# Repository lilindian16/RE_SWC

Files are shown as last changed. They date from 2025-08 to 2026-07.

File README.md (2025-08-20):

# RE_SWC - Car Stereo Volume Knob

_The RE_SWC (Rotary Encoder Steering Wheel Controller) is a plug-and-play kit to add a volume knob back into your car_

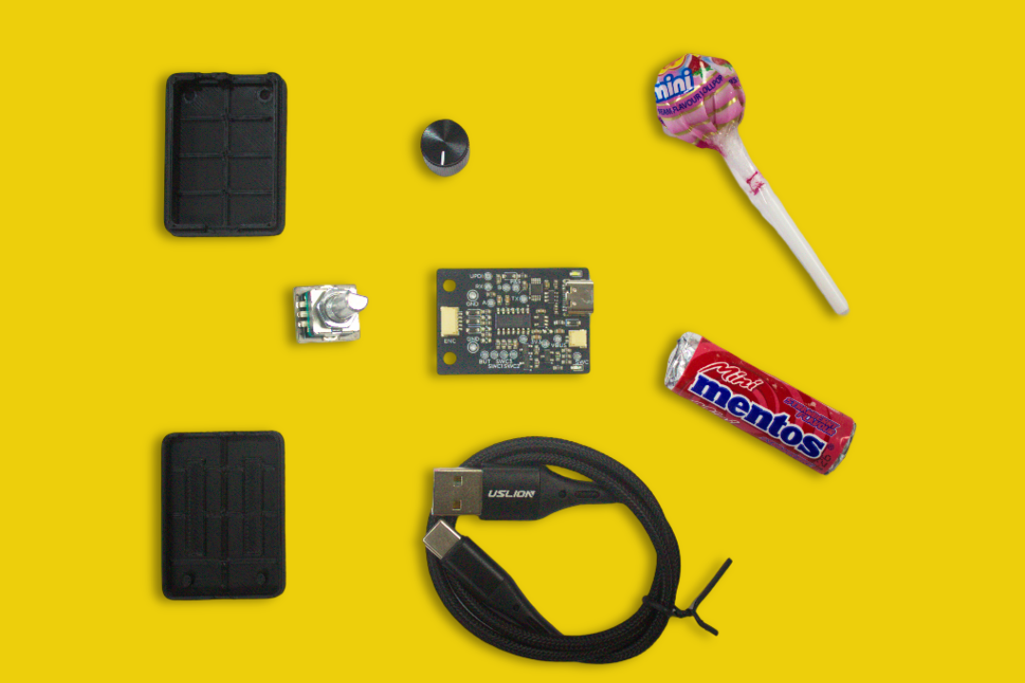
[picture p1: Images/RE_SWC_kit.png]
RE_SWC Product Render




## Features:

- Simple, plug-and-play solution. Mount the volume knob to a panel in the car, solder two wires into your stereo's steering wheel control input and you are good to go
- USB powered. Most headunits have female USB connectors for you to plug this into and power up
- MCU: ATtiny414 - Industrial rated
- Interrupt-driven firmware results in a smooth, user-friendly experience
- Built-in USB to UPDI serial converter for easy programming. If you want to tinker with firmware, do so
- Open source hardware and firmware. This includes all design files, BOM, firmware, etc

## Functions:

- Volume +/-
- Button short press
- Button long press
- Button double press to activate learning mode for headunit

## Compatibility:

The [Hardware Report](https://docs.google.com/spreadsheets/d/1KuhRTHHPlsPpQyRziJOaQv1jJqykjcSSAFU2pcPYcbk/edit?usp=sharing) for this project includes a compatibility matrix. As more people adopt this product, we can build a comprehensive list of compatible devices.

Most headunits supporting steering wheel control input learning/remapping should support this device.

Note: I cannot guarantee this will work with your headunit - there is a decent chance it should if I list it as compatible

## User Guide

The [User Guide](Docs/RE_SWC%20USER%20GUIDE.pdf) can be found in the Docs subfolder of this repository

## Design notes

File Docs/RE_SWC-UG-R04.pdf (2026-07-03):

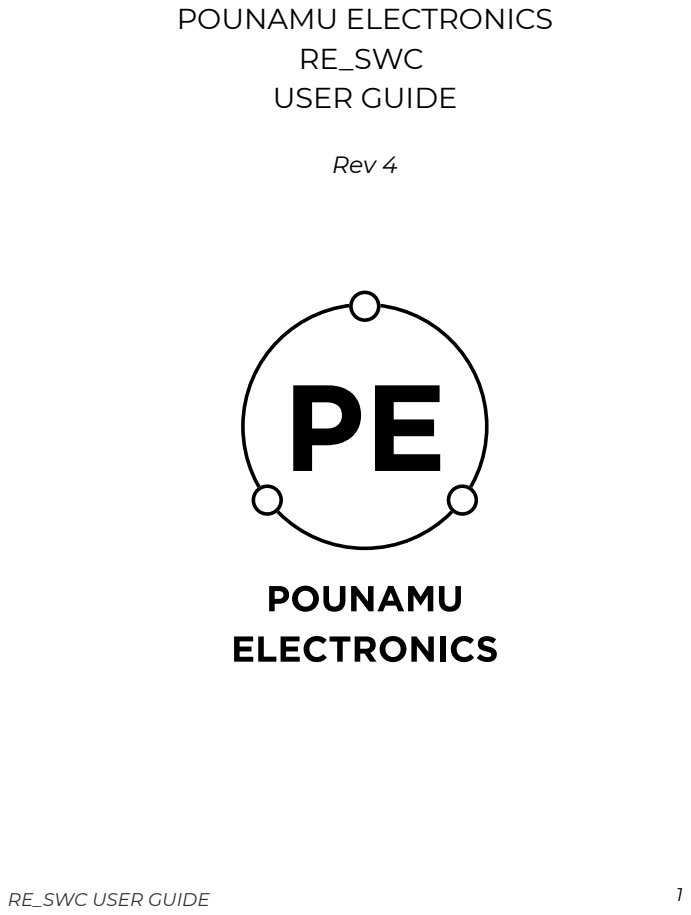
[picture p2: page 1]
RE_SWC USER GUIDE; POUNAMU ELECTRONICS RE_SWC USER GUIDE; Rev 4

3 | OVERVIEW
4 | INSTALLATION GUIDES
| 4 INSTALLATION - GENERIC RESISTIVE
| 5 INSTALLATION - JVC
| 6 INSTALLATION - KENWOOD
| 7 INSTALLATION - ALPINE
| 8 INSTALLATION - PIONEER
| 9 INSTALLATION - USB HID
| 10 INSTALLATION - SONY
11 | CONFIGURATION - HEADUNIT SELECTION
12 | HEADUNIT LEGEND
13 | DEFAULT FUNCTIONS
14 | ASSEMBLY TIPS
15 | VOLUME KNOB DIMESIONS
16 | TROUBLESHOOTING
17 | RE_SWC SPECS
18 | DISCLAIMERS
19 | COMPLIANCE
20 | DOCUMENT REVISION HISTORY

2

### Contents

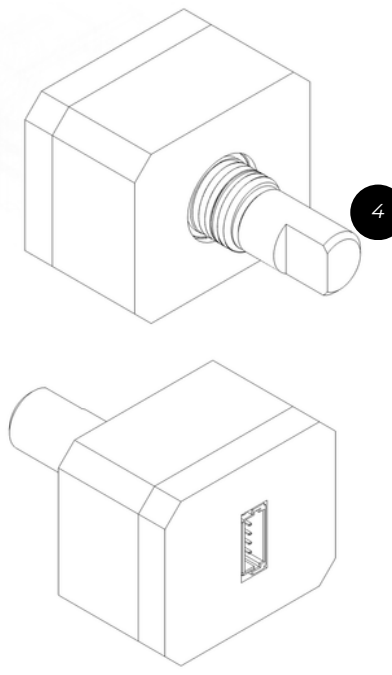
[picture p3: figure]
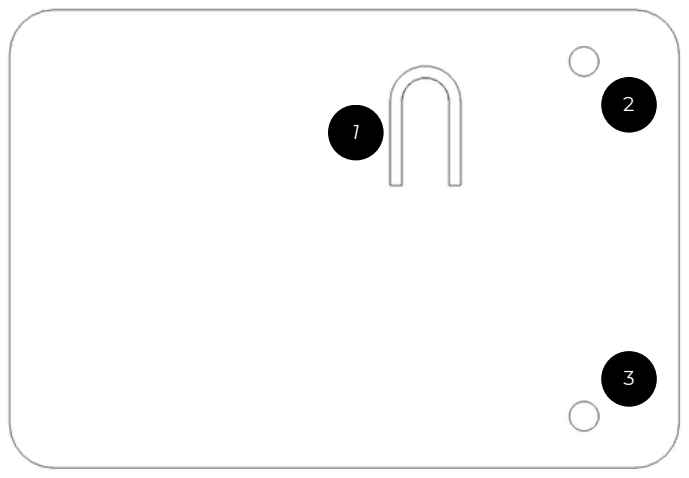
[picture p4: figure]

1. UPDATE BUTTON | 2. WHITE STATUS LIGHT
3. RED POWER LIGHT | 4. DIA 6mm ENCODER SHAFT
RE_SWC USER GUIDE | 3

### OVERVIEW

4

### INSTALLATION - GENERIC RESISTIVE

Solder the RED wire from the 2-pin connector on the RE_SWC kit to your headunit’s steering wheel control input pin (generally labelled KEY1 or KEY2)
If you purchased the 3.5mm patch cable, this will be the tip of the TRS jack
Solder the BLACK wire from the 2-pin connector into your harness if your headunit requires a reference for the SWC input (sometimes labelled ST REMOTE GND)
If you purchased the 3.5mm patch cable, this will be the sleeve of the TRS jack
Power the kit with a USB C cable.
NOTE: This kit requires 5V USB power only The RED power indicator on the RE_SWC will illuminate and stay on

Note: If your headunit requires holding the steering wheel control input when setting functions, double press the volume knob to enter learning mode (indicated with the WHITE status light flashing). The RE_SWC kit will hold the output for 4 seconds
e.g. rotating the knob clockwise once will result in the RE_SWC kit holding the clockwise output for 4 seconds.
Repeat this process to program all functions

5

### INSTALLATION - JVC

Solder the RED wire from the 2-pin connector on the RE_SWC kit to your headunit’s steering wheel control input pin (normally a blue and yellow wire)
If you purchased the 3.5mm patch cable, this will be the tip of the TRS jack
Power the kit with a USB C cable.
NOTE: This kit requires 5V USB power only The RED power indicator on the RE_SWC will illuminate and stay on
The RE_SWC kit will operate without any further configuration on your headunit

6

### INSTALLATION - KENWOOD

Solder the RED wire from the 2-pin connector on the RE_SWC kit to your headunit’s steering wheel control input pin (normally a blue and yellow wire)
If you purchased the 3.5mm patch cable, this will be the tip of the TRS jack
Power the kit with a USB C cable.
NOTE: This kit requires 5V USB power only The RED power indicator on the RE_SWC will illuminate and stay on
The RE_SWC kit will operate without any further configuration on your headunit

7

### INSTALLATION - ALPINE

Plug the RE_SWC into your unit using the 3.5mm patch cable
You can make a compatible 3.5mm patch cable yourself by soldering the red wire from the 2-pin connector on the RE_SWC kit to the tip of the 3.5mm jack. Leave the ring and sleeve floating
Power the kit with a USB C cable.
NOTE: This kit requires 5V USB power only The RED power indicator on the RE_SWC will illuminate and stay on
The RE_SWC kit will operate without any further configuration on your headunit

8

### INSTALLATION - PIONEER

Plug the RE_SWC into your unit using the 3.5mm patch cable
You can make a compatible 3.5mm patch cable yourself by soldering the red wire from the 2-pin connector on the RE_SWC kit to the tip of the 3.5mm jack. Leave the ring and sleeve floating
Power the kit with a USB C cable.
NOTE: This kit requires 5V USB power only The RED power indicator on the RE_SWC will illuminate and stay on
Ensure “With Adapter” is set in the Steering Wheel Controls menu on your headunit
The RE_SWC kit will operate without any further configuration on your headunit

9

### INSTALLATION - USB HID

Connect the RE_SWC kit to your device with a USB C cable (must support data & 5V power) Note: Do not use this device with any power source higher than standard USB 5V
The RED power indicator on the RE_SWC will illuminate and stay on

10

### INSTALLATION - SONY

Plug the RE_SWC into your unit using the 3.5mm patch cable
You can make a compatible 3.5mm patch cable yourself by soldering the red wire from the RE_SWC kit to the tip of the 3.5mm jack. Leave the ring and sleeve floating
Power the kit with a USB C cable.
NOTE: This kit requires 5V USB power only The RED power indicator on the RE_SWC will illuminate and stay on
In the Steering Wheel Controls menu, set the [Custom] switch to [OFF]
On some units, you may need to set it to be “With Adapter”
The RE_SWC kit will operate without any further configuration on your headunit

11

### CONFIGURATION - HEADUNIT SELECTION

Ensure RE_SWC is not powered
Press and hold the volume knob. Connect power to the RE_SWC while keeping the volume knob held
Release the volume knob after the WHITE status light is illuminated
Press the volume knob once. The WHITE status light will flash once. Headunit number 1 is now programmed. Repeat this step until the desired headunit number is reached - refer to the headunit legend
When the desired headunit number is entered, press and hold the volume knob. The WHITE status light will flash. Release the volume knob. The RE_SWC will flash x times where x is the headunit number entered

12

### HEADUNIT LEGEND

HEADUNIT NUMBER | HEADUNIT TYPE / BRAND

1 GENERIC RESISTIVE

2 JVC

3 KENWOOD

4 ALPINE

5 PIONEER

6 USB HID

7 SONY

13

### DEFAULT FUNCTIONS

INPUT | OUTPUT
Volume Knob CW | Volume +
Volume Knob CCW | Volume -
Button Short Press | Mute
Button Long Press | Next Track
Button Double Press (Generic Resistive mode) | Enable Learning Mode
Button Double Press (Other Modes) | Previous Track

RE_SWC USER GUIDE | 14

### ASSEMBLY TIPS

Mounting the knob
Drill a pilot hole between 1 and 3mm in diameter Widen the hole to 7.5mm
Mount the knob into the hole and secure with the included washer and nut

Powering the RE

_

SWC
The RE_SWC uses 5V USB power. Do not use any higher voltage
The RE_SWC boots up almost instantaneously. You can power the device with a switched 5V USB power supply. Configuration settings are retained between power cycles

Note
The RE_SWC will be shipped pre-configured in the mode selected during the checkout process for a plug-and-play setup

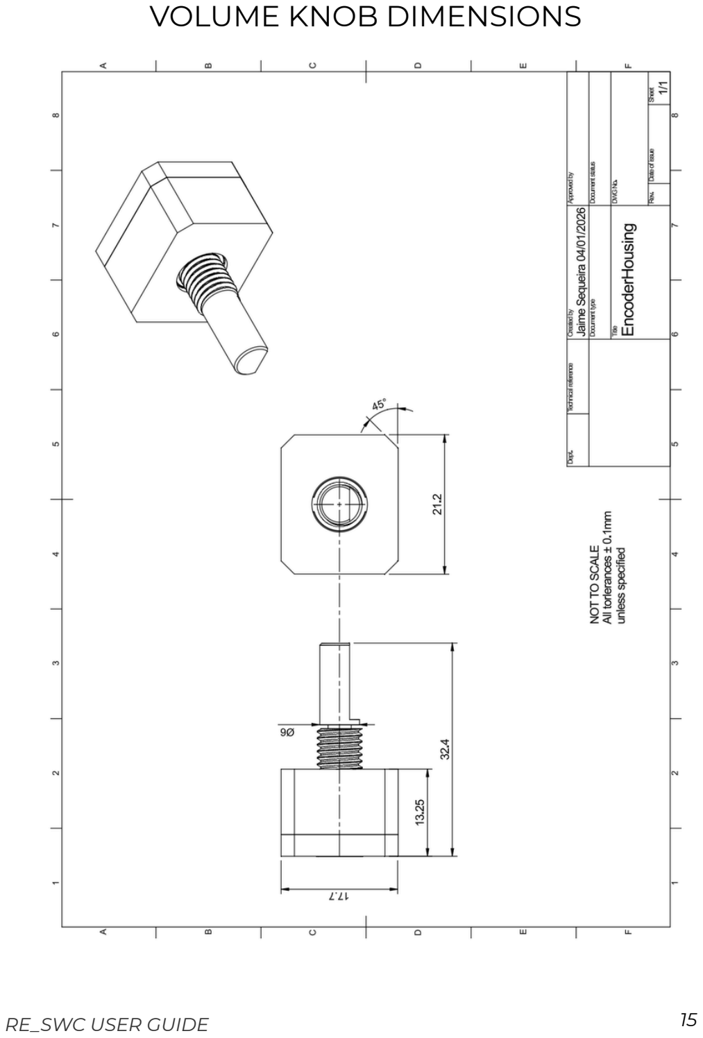
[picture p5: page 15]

RE_SWC USER GUIDE | 15

### VOLUME KNOB DIMENSIONS

16

### TROUBLESHOOTING

The RED power light is off
Ensure you are powering the kit with 5V USB power

The RED power light is on but the WHITE status light does not flash when I use the knob Ensure the 5-pin connector harness for the knob is seated correctly and inserted fully into the knob and the kit

The WHITE status light flashes when I turn the knob but my headunit does nothing
Ensure you have set the kit in the correct headunit mode
Ensure the RED wire from the 2-pin connector is soldered properly into your headunit’s harness

My headunit shows the volume increasing but the volume of my music doesn’t change in USB HID mode
Some Android headunits do not route USB volume commands to the correct hardware. Revert to using the Resistive SWC mode with Key1 / Key 2 input wire instead

### RE_SWC SPECS

Input
Power: 5V / 100mA USB-C
SWC Header: 5V max. Do not connect to 12V signal

CONNECTORS
VOLUME KNOB: JST SHR-05V-S-B SWC OUT: JST SHR-02V-S-B

MCU:
WCH CH32X035F8U6

Digital Rheostat:
MCP4131-104E/SN
SPI @ 250kHz
RE_SWC USER GUIDE | 17

18

### DISCLAIMERS

Pounamu Electronics is not affiliated or associated with any headunit manufacturers or brands
Pounamu Electronics is not affiliated or associated with the USB Implementers Forum (USB-IF)

19

### COMPLIANCE

FCC Compliance Statement
This device complies with Part 15 of the FCC Rules. Operation is subject to the following two
conditions:
1. This device may not cause harmful interference, and
2. this device must accept any interference received, including interference that may cause undesired operation.

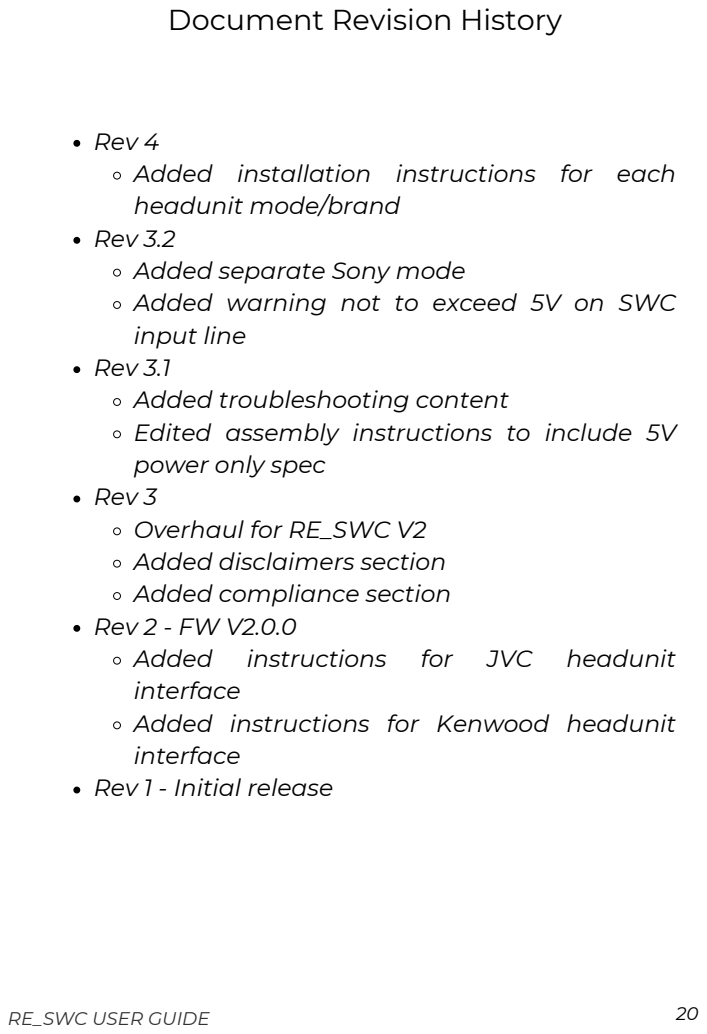
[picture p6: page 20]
RE_SWC USER GUIDE

Document Revision History

Rev 4
Added installation instructions for each
headunit mode/brand
Rev 3.2
Added separate Sony mode
Added warning not to exceed 5V on SWC
input line
Rev 3.1
Added troubleshooting content
Edited assembly instructions to include 5V
power only spec
Rev 3
Overhaul for RE_SWC V2
Added disclaimers section
Added compliance section
Rev 2 - FW V2.0.0
Added instructions for JVC headunit
interface
Added instructions for Kenwood headunit
Rev 1 - Initial release

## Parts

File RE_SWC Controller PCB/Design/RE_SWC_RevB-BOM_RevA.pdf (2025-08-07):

### RE_SWC_RevB - BOM BOM Revision: A

Release: 17/07/2025 Designator | Qty Manufacturer | MPN | LCSC PN Description / Value | Footprint | Datasheet C101,C102,C105,C109 | 4 | YAGEO | CC0603KRX7R9BB104 | C14663 | 100n | C_0603 | https://jlcpcb.com/api/file/downloadByFileSystemAccessId/8579707083955945472 C103,C104 | 2 | Samsung Electro-Mechanics | CL10A106MA8NRNC | C96446 | 10u | C_0603 | https://datasheet.lcsc.com/lcsc/2304140030_Samsung-Electro-Mechanics-CL10A106MA8NRNC_C96446.pdf C106,C107,C108 | 3 | FH (Guangdong Fenghua Advanced Tech) | 0603B103K500NT | C57112 | 10n | C_0603 | https://jlcpcb.com/api/file/downloadByFileSystemAccessId/8579707164920893440 R101,R102,R103,R104,R105,R106,R107,R109,R118,R121,R122 | 11 UNI-ROYAL(Uniroyal Elec) | 0603WAF3300T5E | C23138 | 330R | R_0603 | https://jlcpcb.com/api/file/downloadByFileSystemAccessId/8579706223213461504 R110 | 1 | UNI-ROYAL(Uniroyal Elec) | 0603WAF1001T5E | C21190 | 1k | R_0603 | https://jlcpcb.com/api/file/downloadByFileSystemAccessId/8579706098733010944 R111,R115,R116,R117,R119,R120 | 6 | UNI-ROYAL(Uniroyal Elec) | 0603WAF5101T5E | C23186 | 5k1 | R_0603 | https://jlcpcb.com/api/file/downloadByFileSystemAccessId/8579706277024620544 R112 | 1 | UNI-ROYAL(Uniroyal Elec) | 0603WAF0000T5E | C21189 | 0R | R_0603 | https://jlcpcb.com/api/file/downloadByFileSystemAccessId/8578255895094087680 D101,D109 | 2 | Guangdong Hottech | 1N5819WS | C191023 | 1N5819WS | D_SOD-323_HandSoldering | https://lcsc.com/datasheet/lcsc_datasheet_2409300937_Guangdong-Hottech-1N5819WS_C191023.pdf D102,D105,D106 | 3 | ElecSuper | UDD32C03L01-ES | C5180209 | UDD32C03L01-ES | D_SOD-323_HandSoldering | https://lcsc.com/datasheet/lcsc_datasheet_2504101957_ElecSuper-UDD32C03L01-ES_C5180209.pdf D103 | 1 | Hubei KENTO Elec | KT-0603R | C2286 | LED_RED | LED_0603_HandSolder | https://datasheet.lcsc.com/lcsc/1810231112_Hubei-KENTO-Elec-KT-0603R_C2286.pdf D104 | 1 | Hubei KENTO Elec | KT-0603W | C2290 | LED_WHITE | LED_0603_HandSolder | https://jlcpcb.com/api/file/downloadByFileSystemAccessId/8550724001388785664
F101 | 1 | BHFUSE | BSMD0603-010-24V | C883089 | BSMD0603-010-24V | Fuse_0603_HandSolder | https://www.lcsc.com/datasheet/lcsc_datasheet_2504101957_BHFUSE-BSMD0603-010-24V_C883089.pdf Q101,Q102,Q103 | 3 | Alpha & Omega Semicon | AO3400A | C20917 | AO3400A NMOS | SOT-23 | https://lcsc.com/datasheet/lcsc_datasheet_2410121838_Alpha---Omega-Semicon-AO3400A_C20917.pdf U101 | 1 | Texas Instruments | TPS70933DBVR | C89347 | TPS70933DBVR | SOT-23-5 | https://lcsc.com/datasheet/lcsc_datasheet_2410121952_TI-TPS70933DBVR_C89347.pdf U102 | 1 | Microchip Tech | ATTINY414-SSNR | C189365 | ATtiny414-SSNR | SOIC-14_3.9x8.7mm_P1.27mm | http://ww1.microchip.com/downloads/en/DeviceDoc/40001912A.pdf U103 | 1 | WCH(Jiangsu Qin Heng) | CH340X | C3035748 | CH340X USB UART | MSOP-10_3x3mm_P0.5mm | https://jlcpcb.com/api/file/downloadByFileSystemAccessId/8618866959262109696 U106 | 1 | ST | USBLC6-2SC6 | C7519 | USBLC6-2SC6 | SOT-23-6 | https://lcsc.com/datasheet/lcsc_datasheet_2411121100_TECH-PUBLIC-USBLC6-2SC6_C2827654.pdf
J101 | 1 | G-Switch | GT-USB-7010ASV | C2988369 | GT-USB-7010ASV | G-Switch_GT-USB-7010ASV | https://www.usb.org/sites/default/files/documents/usb_type-c.zip
J104 | 1 | JST | SM05B-SRSS-TB(LF)(SN) | C136657 | SM05B-SRSS-TB | JST_SH_SM05B-SRSS-TB | https://lcsc.com/product-detail/Wire-To-Board-Connector_JST-SM05B-SRSS-TB-LF-SN_C136657.html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,JST%20SM05B%2DSRSS%2DTB(LF)(SN),-Custom%20Cables
J106 | 1 | JST | SM02B-SRSS-TB(LF)(SN) | C160402 | SM02B-SRSS-TB | JST_SH_SM02B-SRSS-TB | https://www.lcsc.com/datasheet/lcsc_datasheet_2304140030_JST-SM02B-SRSS-TB-LF-SN_C160402.pdf

Revision Notes Rev A: Initial release

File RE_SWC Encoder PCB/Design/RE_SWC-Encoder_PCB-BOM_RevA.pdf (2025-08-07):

RE_SWC-Encoder_PCB - BOM
BOM Revision: A
Release: 17/07/2025 Designator | Qty Manufacturer | MPN | LCSC PN Description / Value | Footprint | Datasheet
SW101 | 1 | CTR | ED11305M-FB18.5A10-E20-160-G219 | C19712528 Rotary Encoder | Rotary_Encoder:RotaryEncoder_Bourns_Vertical_PEC12R-3x17F-Sxxxx | https://lcsc.com/datasheet/lcsc_datasheet_2410121342_CTR-ED11305M-FB18-5A10-E20-160-G219_C19712528.pdf
J101 | 1 | JST | BM05B-SRSS-TBT(LF)(SN) | C265092 | BM05B-SRSS-TBT(LF)(SN) | Connector_JST:JST_SH_BM05B-SRSS-TB_1x05-1MP_P1.00mm_Vertical | https://www.lcsc.com/datasheet/lcsc_datasheet_2004071004_JST-BM05B-SRSS-TBT-LF-SN_C265092.pdf

Revision Notes
Rev A: Initial release

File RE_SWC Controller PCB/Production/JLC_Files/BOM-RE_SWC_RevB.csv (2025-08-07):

Comment | Designator | Footprint | LCSC | Quantity
SM05B-SRSS-TB | J104 | JST_SH_SM05B-SRSS-TB_1x05-1MP_P1.00mm_Horizontal | C136657 | 1
100n | C102,C105,C109 | C_0603_1608Metric | C14663 | 3
SM02B-SRSS-TB | J106 | JST_SH_SM02B-SRSS-TB_1x02-1MP_P1.00mm_Horizontal | C160402 | 1
ATtiny414-SSNR | U102 | SOIC-14_3.9x8.7mm_P1.27mm | C189365 | 1
1N5819WS | D101,D109 | D_SOD-323_HandSoldering | C191023 | 2
AO3400A | Q101,Q102,Q103 | SOT-23 | C20917 | 3
0R | R112 | R_0603_1608Metric | C21189 | 1
1k | R110 | R_0603_1608Metric | C21190 | 1
LED_RED | D103 | LED_0603_1608Metric_Pad1.05x0.95mm_HandSolder | C2286 | 1
LED_WHITE | D104 | LED_0603_1608Metric_Pad1.05x0.95mm_HandSolder | C2290 | 1
330R | R101,R102,R103,R104,R105,R106,R107,R109,R118,R121,R122 | R_0603_1608Metric | C23138 | 11
5k1 | R111,R115,R116,R117,R119,R120 | R_0603_1608Metric | C23186 | 6
GT-USB-7010ASV | J101 | USB_C_Receptacle_G-Switch_GT-USB-7010ASV | C2988369 | 1
CH340X | U103 | MSOP-10_3x3mm_P0.5mm | C3035748 | 1
UDD32C03L01-ES | D102,D105,D106 | D_SOD-323_HandSoldering | C5180209 | 3
10n | C106,C107,C108 | C_0603_1608Metric | C57112 | 3
USBLC6-2SC6 | U106 | SOT-23-6 | C7519 | 1
BSMD0603-010-24V | F101 | Fuse_0603_1608Metric_Pad1.05x0.95mm_HandSolder | C883089 | 1
TPS70933DBVR | U101 | SOT-23-5 | C89347 | 1
10u | C103,C104 | C_0603_1608Metric | C96446 | 2

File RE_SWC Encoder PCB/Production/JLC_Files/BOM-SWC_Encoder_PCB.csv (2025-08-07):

Comment | Designator | Footprint | LCSC | Quantity
Rotary Encoder | SW101 | RotaryEncoder_Bourns_Vertical_PEC12R-3x17F-Sxxxx | C19712528 | 1
BM05B-SRSS-TBT(LF)(SN) | J101 | JST_SH_BM05B-SRSS-TB_1x05-1MP_P1.00mm_Vertical | C265092 | 1

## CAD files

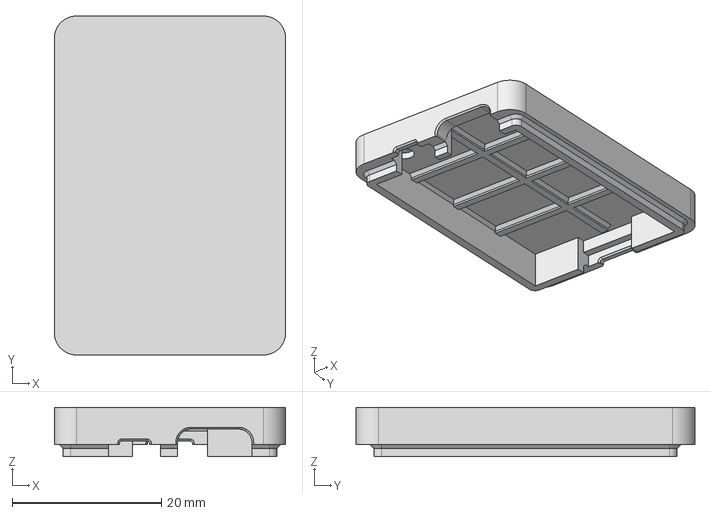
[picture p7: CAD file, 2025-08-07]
RE_SWC Case/FDM/STEP/RE_SWC_FDM_Case_Lid.step
31.0 x 45.4 x 6.60 mm

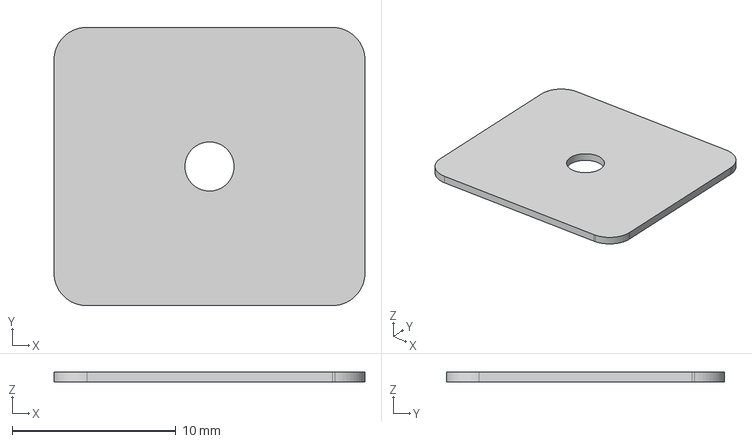
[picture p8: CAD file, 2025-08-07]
RE_SWC Drill Template/RE_SWC_Drill_Template.step
19.0 x 17.0 x 0.6 mm

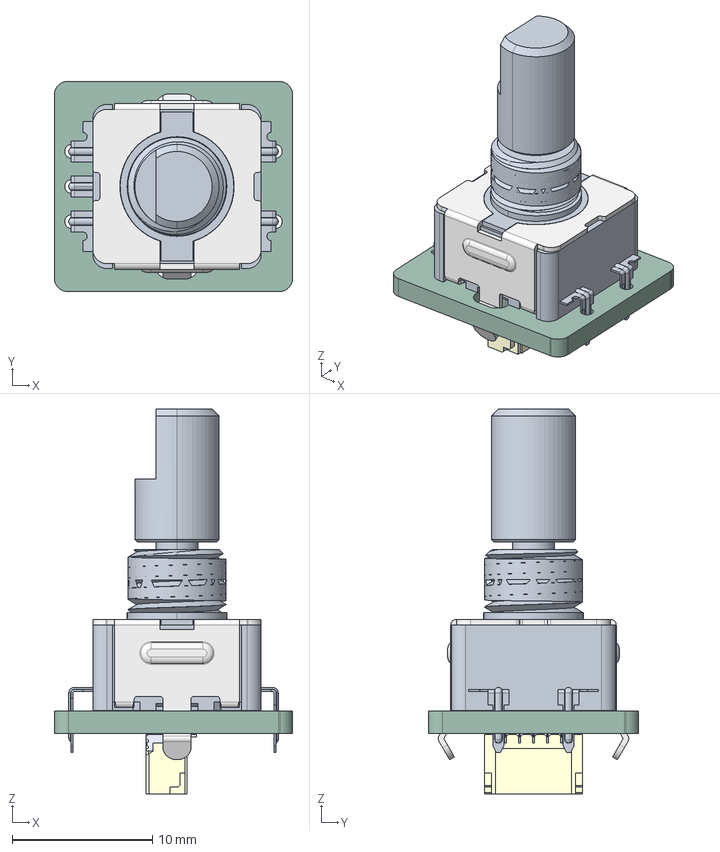
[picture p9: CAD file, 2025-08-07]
RE_SWC Encoder PCB/Design/RE_SWC_Encoder_PCB_RevA.step
17.0 x 15.0 x 27.5 mm
PEC11H-4015F-S0016
BM05B-SRSS-TB(LF)(SN)
SWC_Encoder_PCB_PCB

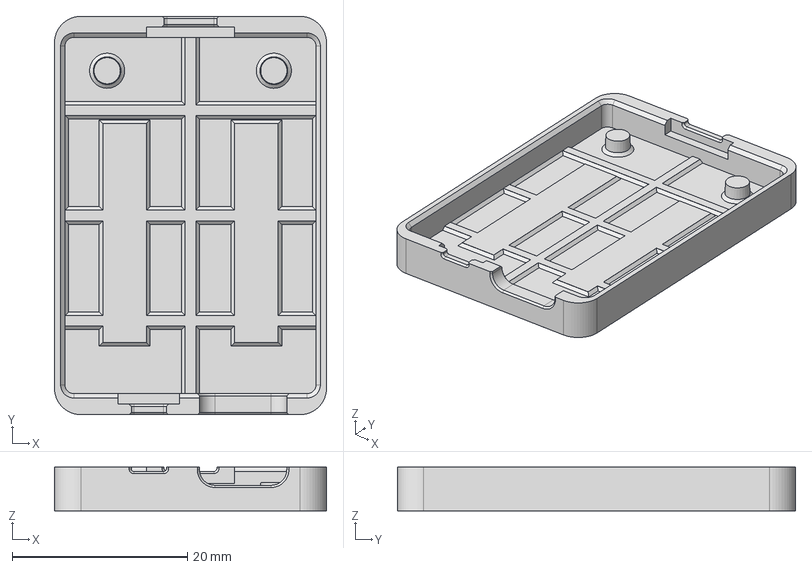
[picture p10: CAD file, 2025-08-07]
RE_SWC Case/FDM/STEP/RE_SWC_FDM_Case_Base.step
31.0 x 45.4 x 5.00 mm

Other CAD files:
RE_SWC Case/FDM/STL/RE_SWC_FDM_Case_Base.stl
RE_SWC Case/FDM/STL/RE_SWC_FDM_Case_Lid.stl
RE_SWC Drill Template/RE_SWC_Drill_Template.stl

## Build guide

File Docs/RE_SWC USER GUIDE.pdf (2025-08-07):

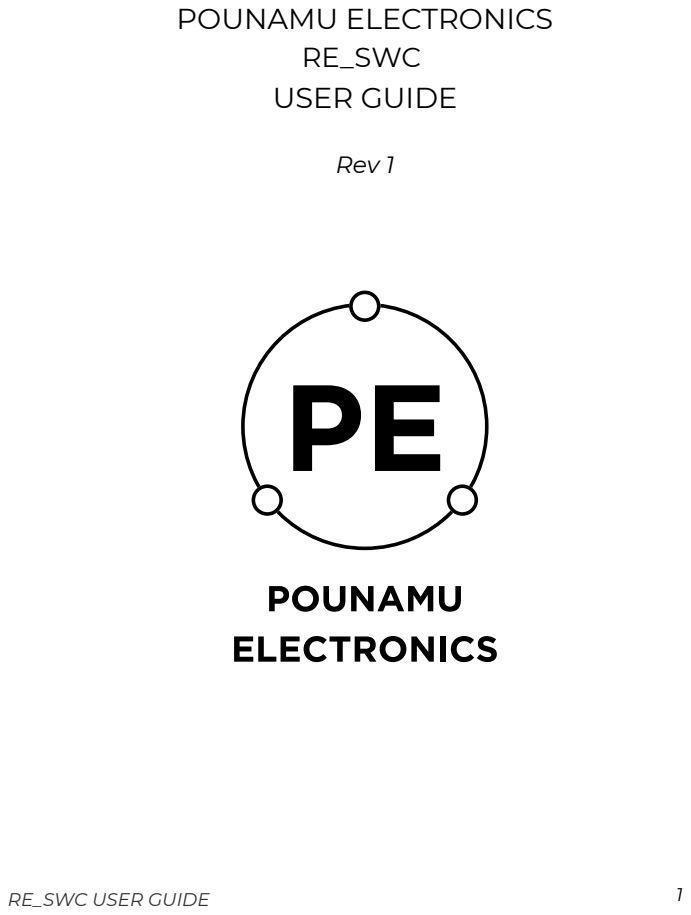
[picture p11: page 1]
RE_SWC USER GUIDE; POUNAMU ELECTRONICS RE_SWC USER GUIDE; Rev 1

3 | OVERVIEW - CONTROLLER BOARD
4 | OVERVIEW - VOLUME KNOB BOARD
5 | ASSEMBLY - STEERING WHEEL CONTROL OUTPUT
6 | ASSEMBLY - VOLUME KNOB CONNECTION
7 | ASSEMBLY - CASE
8 | ASSEMBLY - POWER
9 | HEADUNIT LEARNING - TYPE 1
10 | HEADUNIT LEARNING - TYPE 2
11 | SWC OUTPUT RESISTORS
12 | RE_SWC SPECS
13 | Document Revision History

2

### Contents

1

2

3

4

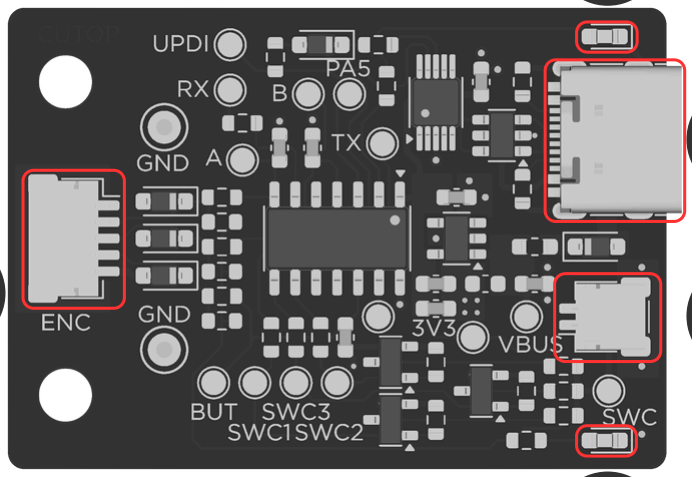
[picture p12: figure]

5

1. VOLUME KNOB CONNECTOR | 2. WHITE STATUS LIGHT
3. USB DATA & POWER IN | 4. STEERING WHEEL CONTROL OUTPUT

### 5. RED POWER LIGHT

RE_SWC USER GUIDE | 3

### OVERVIEW

CONTROLLER BOARD

### OVERVIEW

VOLUME KNOB BOARD

2

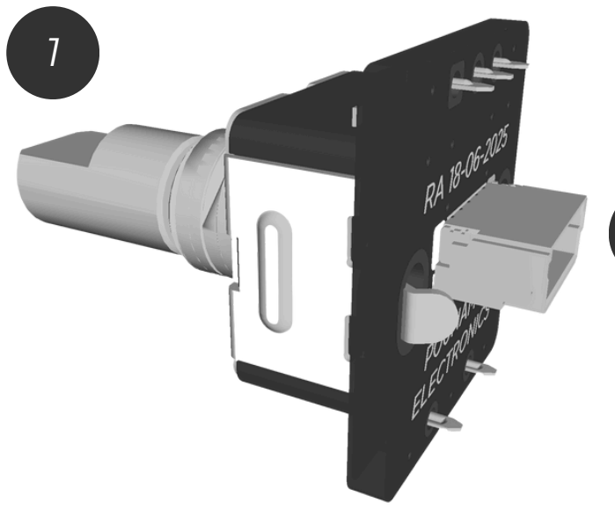
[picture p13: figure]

### 1. VOLUME KNOB

### 2. VOLUME KNOB

CONNECTOR

RE_SWC USER GUIDE | 4

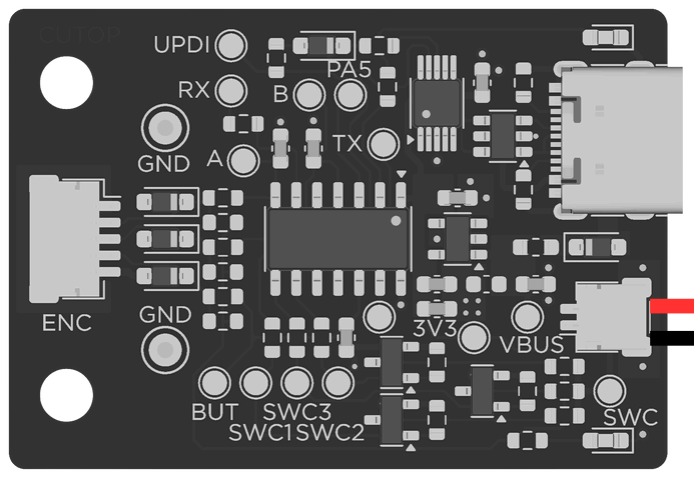
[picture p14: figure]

RE_SWC USER GUIDE | 5

### ASSEMBLY

STEERING WHEEL CONTROL OUTPUT

Solder RE_SWC steering wheel control output to headunit steering wheel control input
RED wire to headunit steering wheel control input (KEY)
BLACK wire to headunit ground
Plug the connector into RE_SWC

GND HEADUNIT

KEY

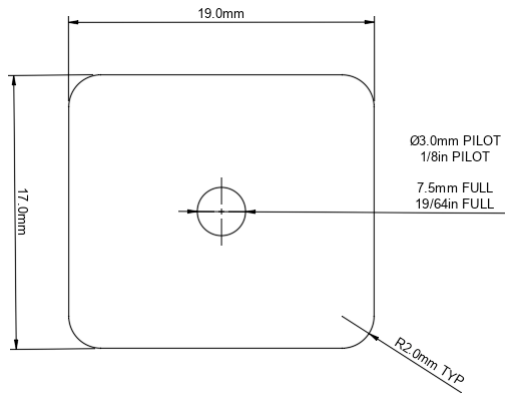
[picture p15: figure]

RE_SWC USER GUIDE | 6

Locate an area to fit your volume knob. Use the drilling template as a guide for clearance
Use the drilling template included in the box or shown below to create a 3mm (1/8in) pilot hole for the volume knob
Open the pilot hole with a 7.5mm (19/64in) drill bit
Plug the 5-pin connector into the volume knob board
Mount the volume knob to your panel. Secure it with the washer and nut included in the kit Plug the 5-pin volume knob connector into RE_SWC

### ASSEMBLY

VOLUME KNOB CONNECTION

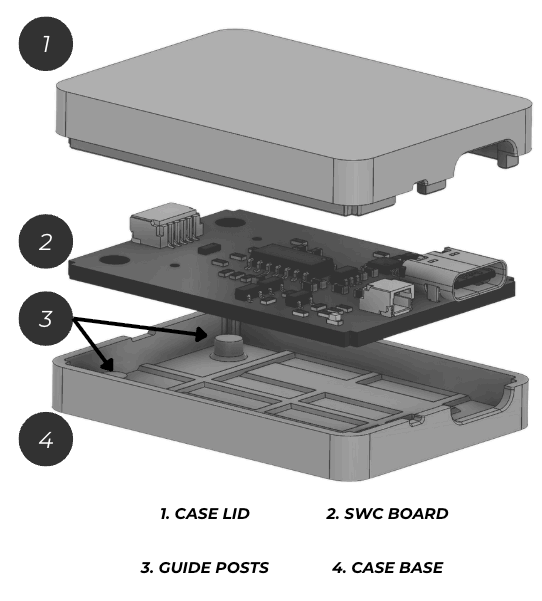
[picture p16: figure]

Ensure the volume knob and SWC output connectors are connected to the controller before proceeding
Lower the SWC board into the case base using the guide posts for alignment and press into place. The volume knob and SWC output connectors will sit flush to the inside edge of the case
Press the case lid into the case base. It should be a tight, snap fit. The connectors will be captive inside the case, unable to be pulled out
RE_SWC USER GUIDE | 7

### ASSEMBLY

CASE

8

### ASSEMBLY

POWER

Plug the included USB-C cable into the RE_SWC When the RE_SWC is powered, the RED power light will illuminate
When working correctly, rotating the volume knob or pressing the volume knob button will result in the WHITE status light illuminating briefly
If the WHITE status light does not illuminate, ensure the volume knob connector is fully seated into both the controller and volume knob boards

### HEADUNIT LEARNING Type 1

Headunit Learning Type 1 is used with headunits that require momentary inputs when learning SWC functions

Open the Steering Wheel Control learning app/setting on your headunit
Select the function you want to program on the headunit e.g. Volume+
Perform the action with your volume knob e.g. for Volume+

, rotate the volume knob clockwise one step
The headunit will confirm that the function has been programmed
Repeat for all required functions
Volume+/-
Button Short Press
Button Long Press
RE_SWC USER GUIDE | 9

10

### HEADUNIT LEARNING Type 2

Headunit Learning Type 2 is used with headunits that require inputs to be held during SWC learning

Enable learning mode on RE_SWC controller by double-pressing the volume knob
The RE_SWC will confirm learning mode is enabled by rapidly flashing the WHITE status light
Select the function you want to program on the headunit e.g. Volume+
Perform the action with your volume knob e.g. for Volume+

, rotate the volume knob clockwise one step
The WHITE status light will illuminate for 4 seconds while the output is held.

IMPORTANT: Do not touch the SWC or headunit during this time to allow the headunit to configure itself

Once the function is programmed, the WHITE status light will be turned off
Repeat for all required functions
Volume+/-
Button Short Press
Button Long Press

11

### SWC OUTPUT RESISTORS

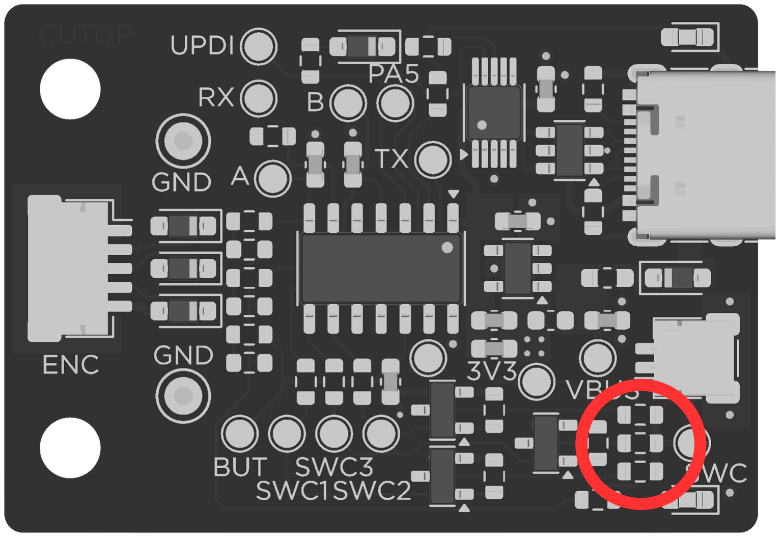
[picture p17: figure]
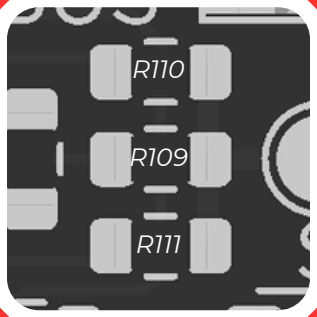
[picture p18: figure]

RESISTOR ID | VALUE | OUTPUT
R110 | 1kΩ ± 1% | SWC OUT 2
R109 | 330Ω ± 1% | SWC OUT 1
R111 | 5.1kΩ ± 1% | SWC OUT 3

### RE_SWC SPECS

Input
5V USB-C
300mA AUTO RESETTING FUSE

Output
SWC OUT 1: 330Ω ± 1%
SWC OUT 2: 1kΩ ± 1%
SWC OUT 3: 5.1kΩ ± 1%

CONNECTORS
VOLUME KNOB: JST SHR-05V-S-B SWC OUT: JST SHR-02V-S-B

MCU:
MICROCHIP ATTINY414
AVR 1 Series
RE_SWC USER GUIDE | 12

### Document Revision History

Rev 1 - Initial release

RE_SWC USER GUIDE | 13

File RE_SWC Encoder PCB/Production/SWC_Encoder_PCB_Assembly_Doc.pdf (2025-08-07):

No | Not specified | 0.01 | mm

# Min hole diameter: Not specified

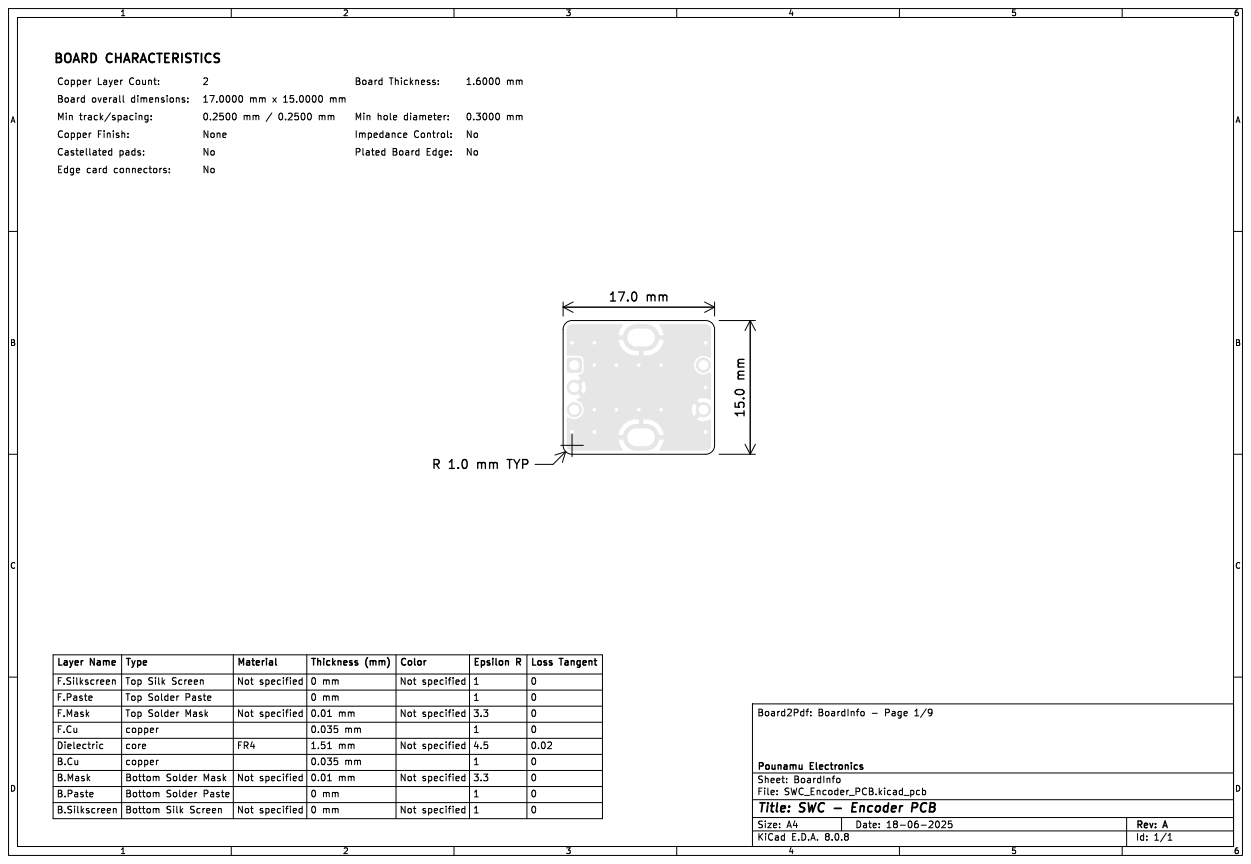
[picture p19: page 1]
D Date: 18-06-2025 KiCad; E.D.A. 8.0.8 Size: A4; Rev: A; File: SWC_Encoder_PCB.kicad_pcb Sheet: BoardInfo Pounamu; Electronics Board2Pdf:; BoardInfo; Page; Board; Thickness:; Impedance; Control:; B.Paste; Edge card; connectors:; Not specified; B.Mask; Epsilon; Board overall; dimensions:; Castellated; pads:; BOARD CHARACTERISTICS; Copper Finish:; None; R 1.0 mm TYP

Copper Layer Count:
Min track/spacing:

Plated Board Edge:

Top Solder Paste | | 0 mm | | | 0 F.Mask Dielectric Layer Name F.Paste F.Cu

Bottom Solder Mask F.Silkscreen | | Screen Top Solder | Screen Mask | | Not specified | | Thickness | (mm) | Color Bottom Silk Not specified B.Silkscreen Not specified | 1 Not specified B.Cu 3.3 | 0 Top Silk 0

Type
copper | | 0.035 mm | | 1 Not specified FR4 | 0

Loss Tangent 1 Material

copper core | | | | | 1 Bottom Solder Paste 4.5

0.035 mm | | | | 0.02 Not specified 0

0.01 mm | | | 3.3 | 0
0 mm | | 1
0 mm | | | 0

Id: 1/1 Title: SWC - Encoder PCB

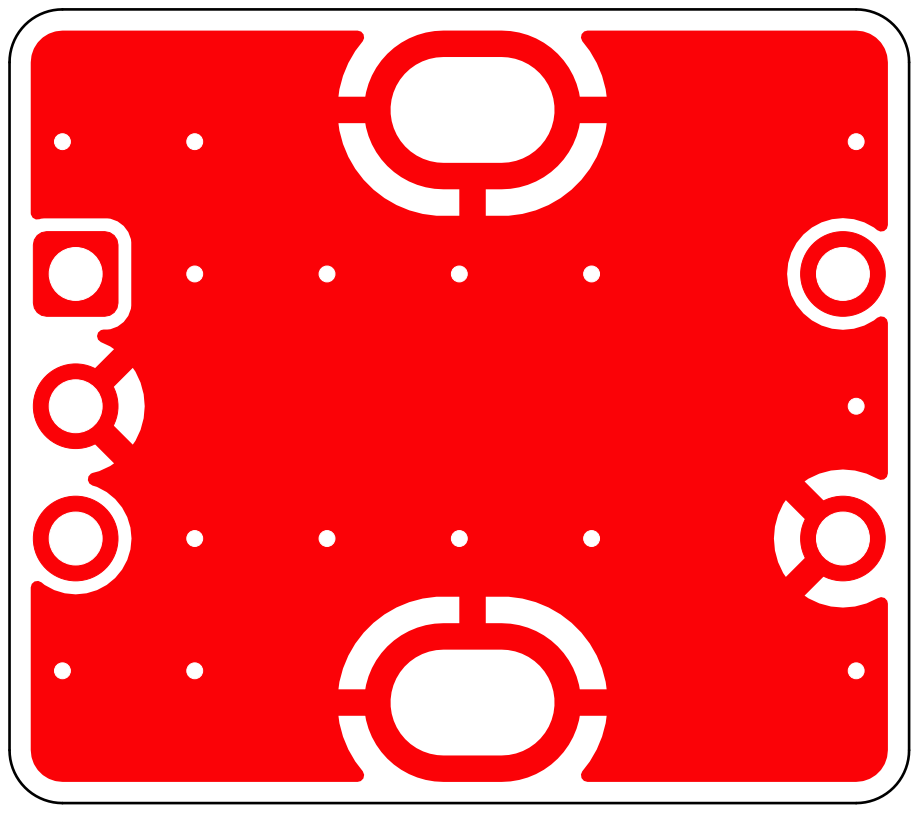
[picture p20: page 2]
6 ABCD; ABCD Date: 18-06-2025 KiCad; E.D.A. 8.0.8 Size: A4; Rev: A; Pounamu; Electronics Board2Pdf:; FrontCU -; Page 2/9

File: SWC_Encoder_PCB.kicad_pcb Sheet: FrontCU
Id: 1/1 Title: SWC - Encoder PCB

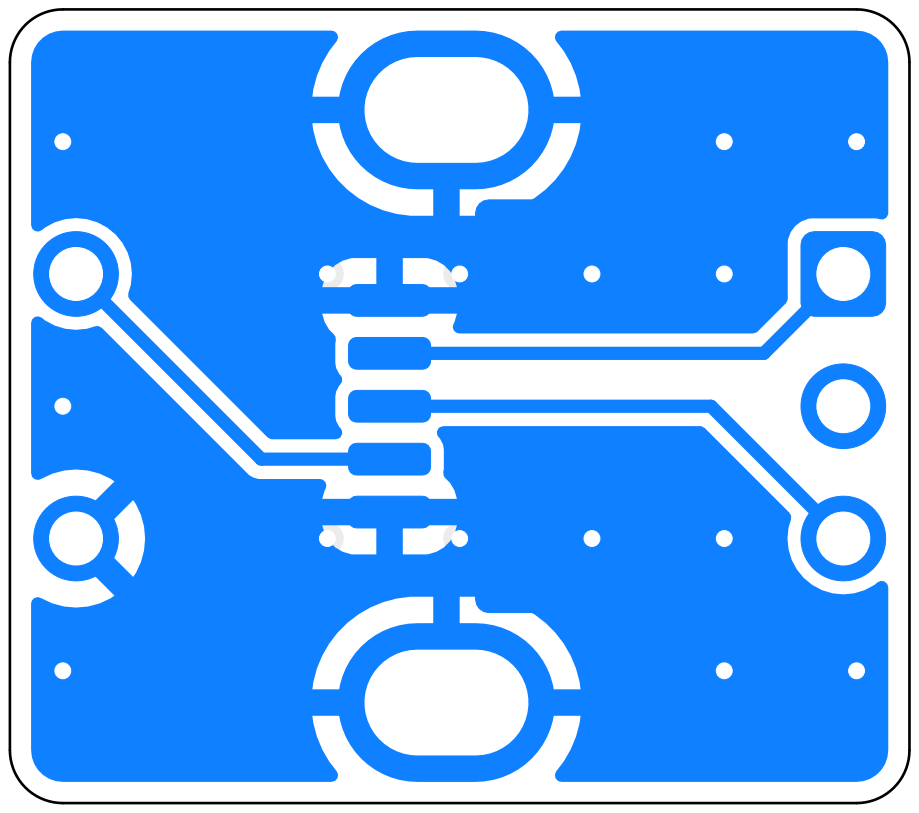
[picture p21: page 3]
6 ABCD; ABCD Date: 18-06-2025 KiCad; E.D.A. 8.0.8 Size: A4; Rev: A; Pounamu; Electronics Board2Pdf:; BackCU -; Page 3/9

File: SWC_Encoder_PCB.kicad_pcb Sheet: BackCU
Id: 1/1 Title: SWC - Encoder PCB

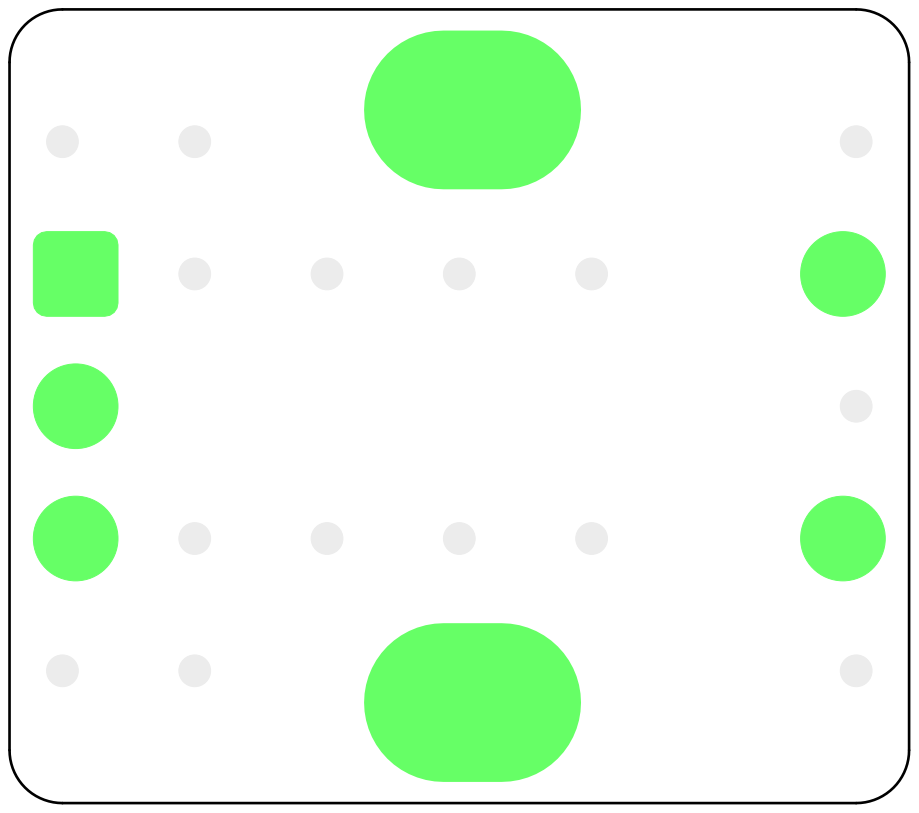
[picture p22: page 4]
6 ABCD; ABCD Date: 18-06-2025 KiCad; E.D.A. 8.0.8 Size: A4; Rev: A; File: SWC_Encoder_PCB.kicad_pcb Sheet: FrontMask Pounamu; Electronics Board2Pdf:; FrontMask; Page 4/9

Id: 1/1 Title: SWC - Encoder PCB

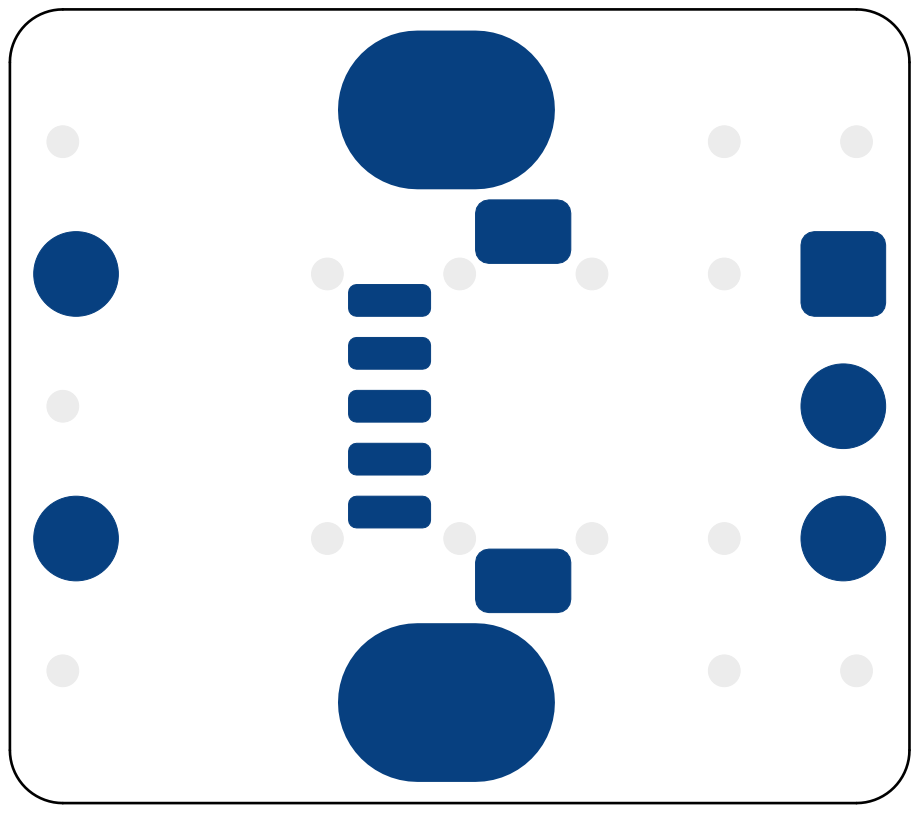
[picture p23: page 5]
6 ABCD; ABCD Date: 18-06-2025 KiCad; E.D.A. 8.0.8 Size: A4; Rev: A; File: SWC_Encoder_PCB.kicad_pcb Sheet: BackMask Pounamu; Electronics Board2Pdf:; BackMask; Page 5/9

Id: 1/1 Title: SWC - Encoder PCB

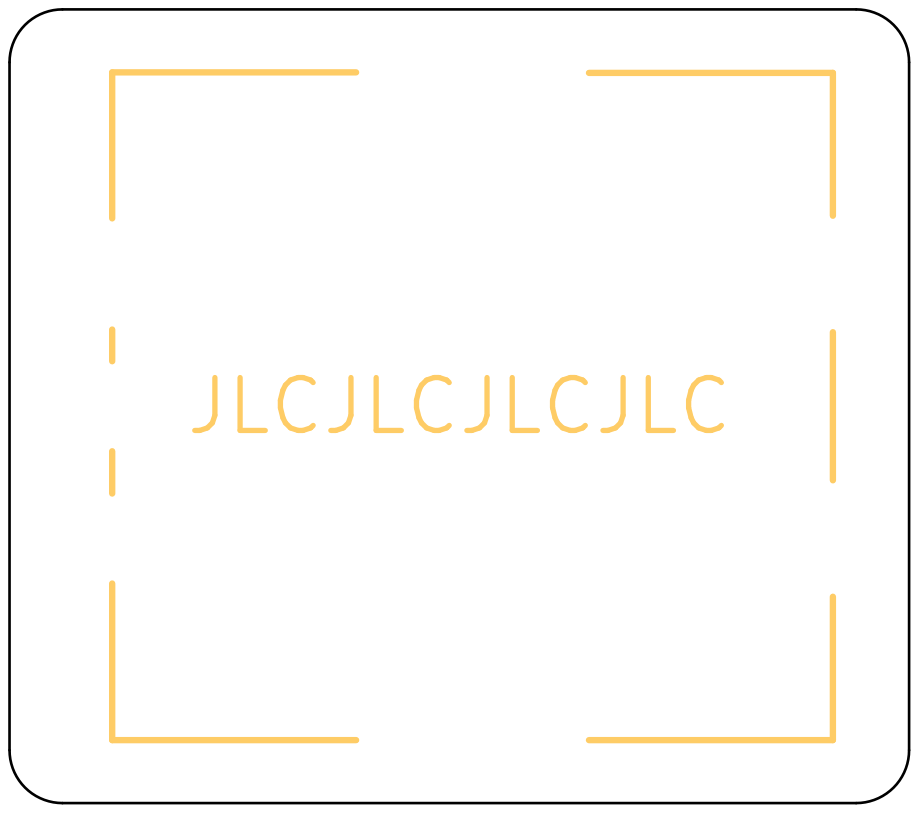
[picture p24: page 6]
6 ABCD; ABCD Date: 18-06-2025 KiCad; E.D.A. 8.0.8 Size: A4; Rev: A; Pounamu; Electronics Board2Pdf:; FrontSS -; Page 6/9; JLCJLCJLCJLC

File: SWC_Encoder_PCB.kicad_pcb Sheet: FrontSS
Id: 1/1 Title: SWC - Encoder PCB

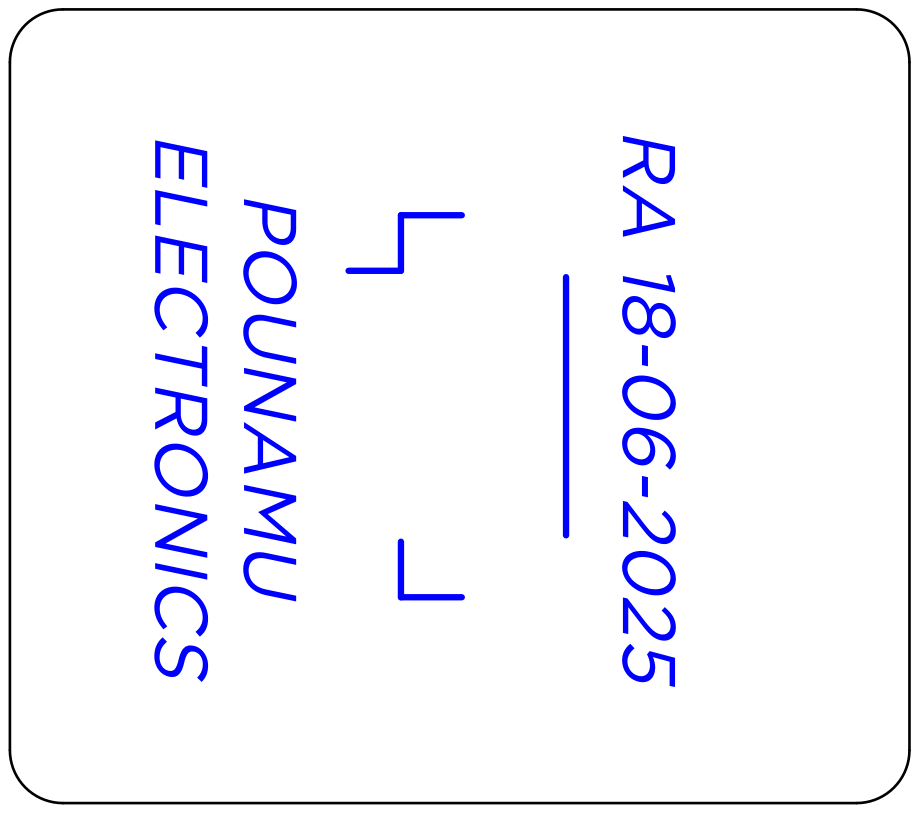
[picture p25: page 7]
6 ABCD; ABCD Date: 18-06-2025 KiCad; E.D.A. 8.0.8 Size: A4; Rev: A; Pounamu; Electronics Board2Pdf:; BackSS -; Page 7/9

File: SWC_Encoder_PCB.kicad_pcb Sheet: BackSS
Id: 1/1 Title: SWC - Encoder PCB

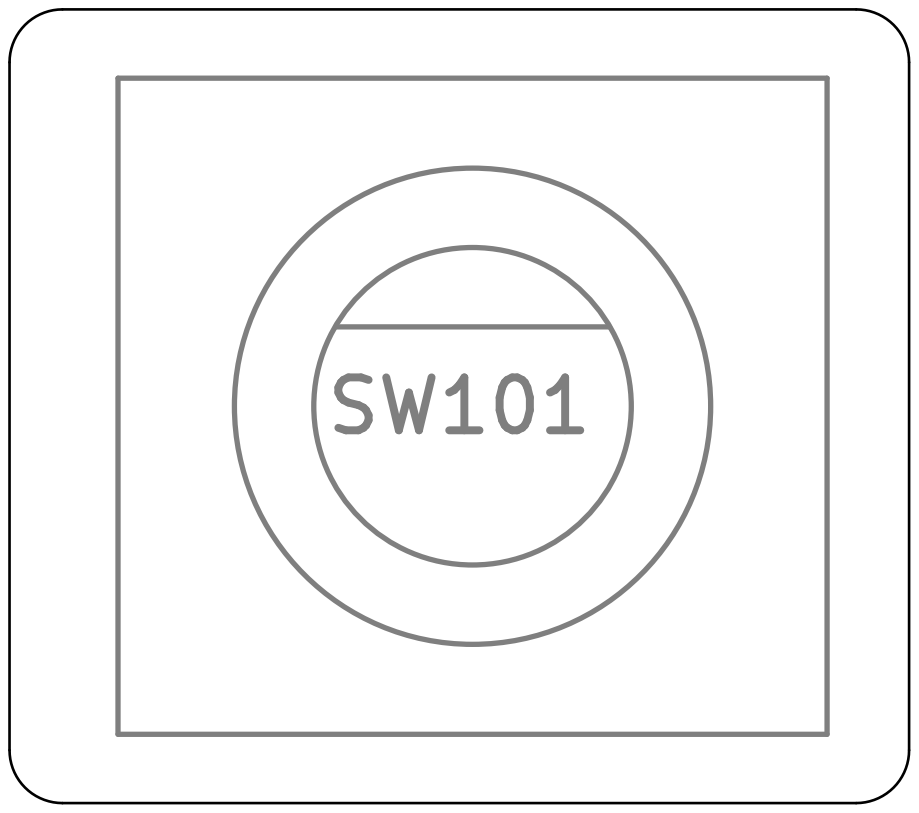
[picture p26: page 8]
6 ABCD; ABCD Date: 18-06-2025 KiCad; E.D.A. 8.0.8 Size: A4; Rev: A; File: SWC_Encoder_PCB.kicad_pcb Sheet: FrontFab Pounamu; Electronics Board2Pdf:; FrontFab; Page 8/9

Id: 1/1 Title: SWC - Encoder PCB

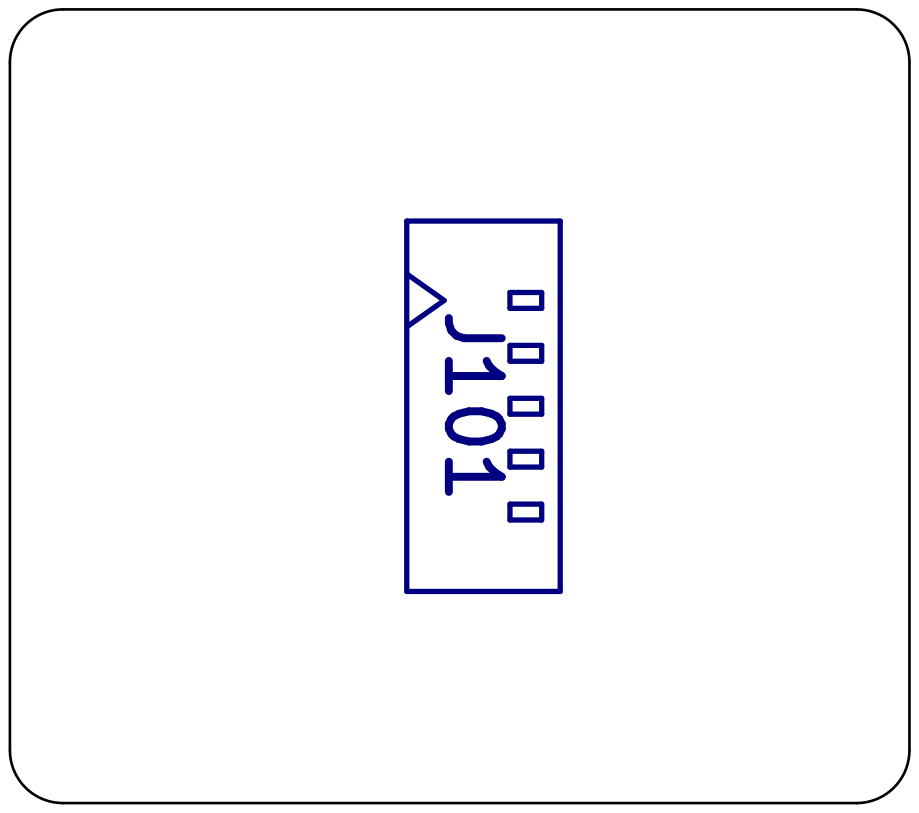
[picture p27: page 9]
6 ABCD; ABCD Date: 18-06-2025 KiCad; E.D.A. 8.0.8 Size: A4; Rev: A; File: SWC_Encoder_PCB.kicad_pcb Sheet: BackFab Pounamu; Electronics Board2Pdf:; BackFab; Page 9/9 J101

Id: 1/1 Title: SWC - Encoder PCB

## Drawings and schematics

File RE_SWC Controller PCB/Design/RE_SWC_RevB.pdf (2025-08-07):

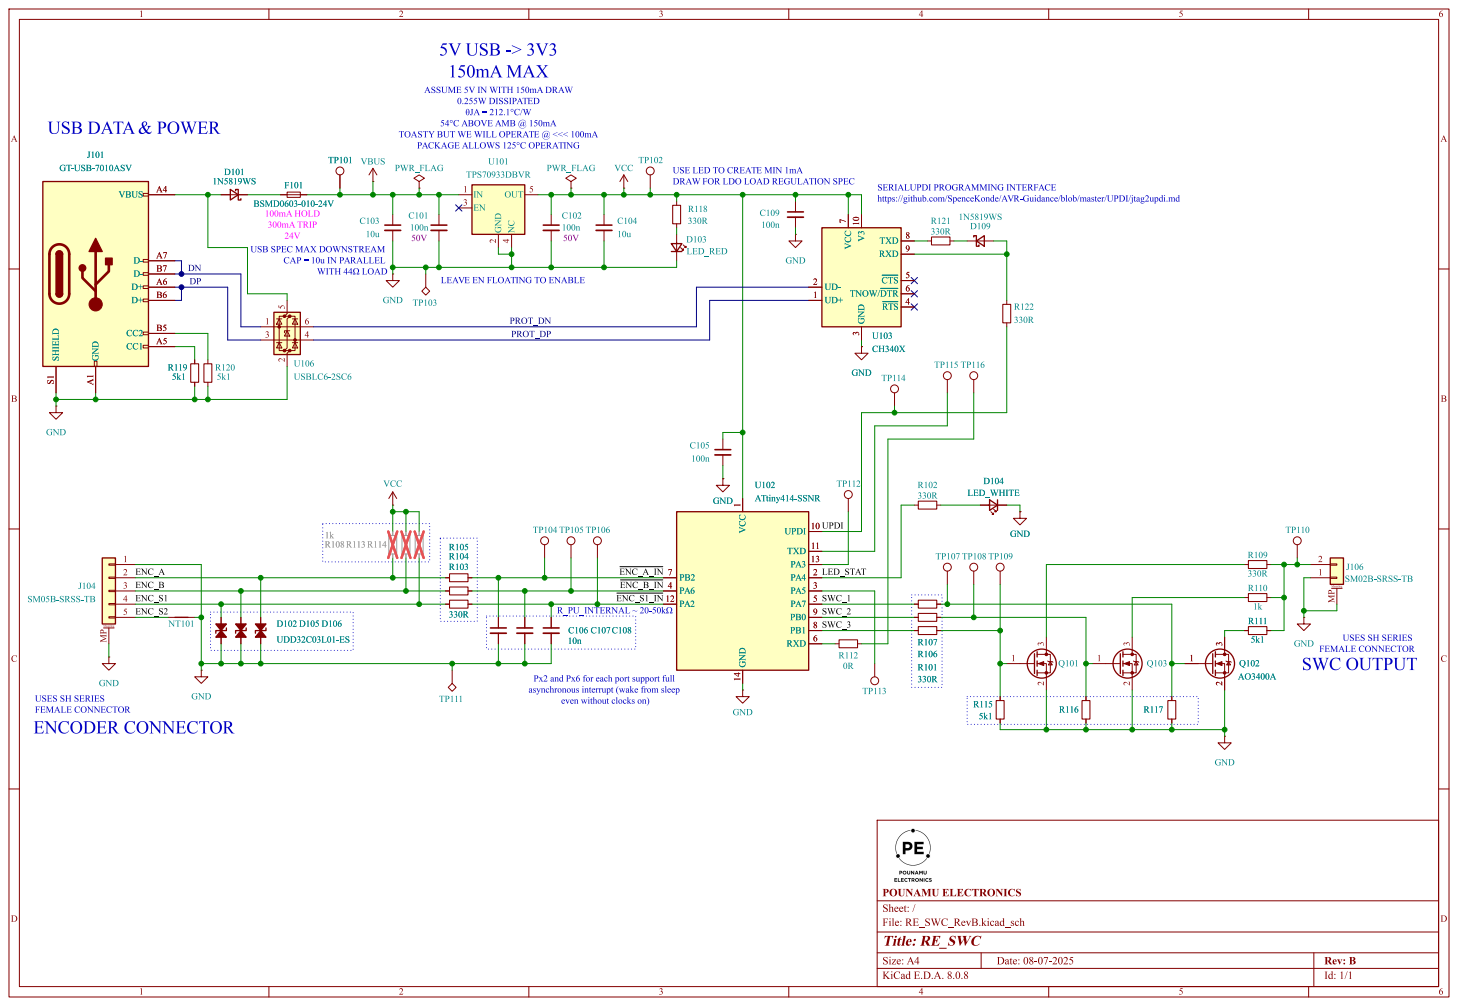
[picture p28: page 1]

PACKAGEALLOWS þÿ125°C OPERATING 5V USB-> 3V3
150mAMAX

TOASTYBUT WE WILL OPERATE@<<< 100mA

USELED TO CREATEMIN 1mA DRAW FORLDO LOAD REGULATIONSPEC

https://github.com/SpenceKonde/AVR-Guidance/blob/master/UPDI/jtag2updi.md USBSPECMAX DOWNSTREAM
100mAHOLD
300mATRIP

3 ~{RTS}4 ~{CTS}5 TNOW/~{DTR}6 VCC

CAP= 10uIN PARALLEL WITH þÿ44© LOAD

1 UPDI 10 TXD 11 PA2 12 PA3 13 GND 14 PA4 2 PA5 3 PA6 4 PA7 5 RXD 6 PB2 7 PB1 8 PB0 9 U102 ATtiny414-SSNR

1 UPDI 10 TXD 11 PA2 12 PA3 13 GND 14 PA4 2 PA5 3 PA6 4 PA7 5 RXD 6 PB2 7 PB1 8 PB0 9 GND

ENC_S1 ENC_A 3 ENC_B | ~{ENC_B_IN}

Px2andPx6for eachport supportfull asynchronousinterrupt(wakefrom sleep

File: RE_SWC_RevB.kicad_sch Sheet:/ POUNAMU ELECTRONICS

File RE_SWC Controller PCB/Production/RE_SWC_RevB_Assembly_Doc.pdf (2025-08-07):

Copper | Layer Count: Board | overall | dimensions: | White White F.Silkscreen

### BOARD CHARACTERISTICS

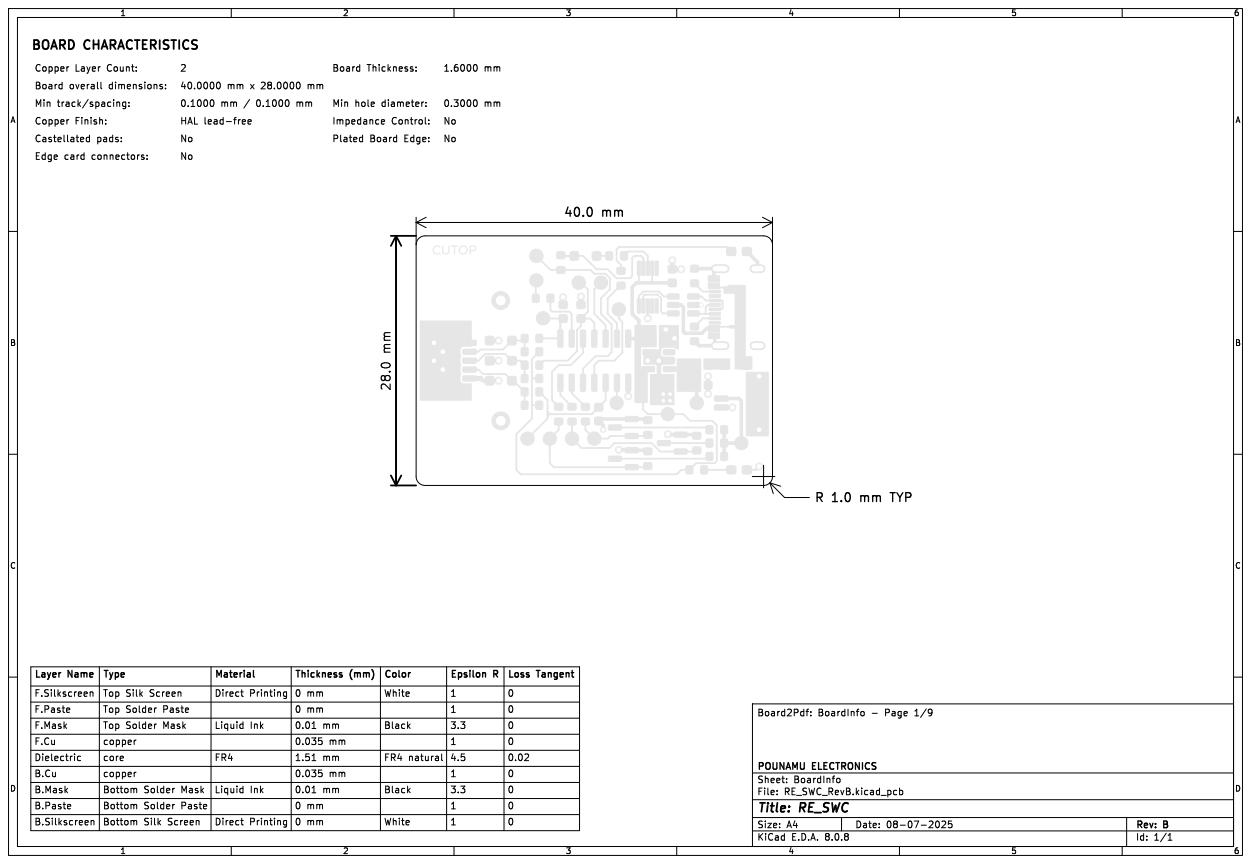
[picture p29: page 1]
D Date: 08-07-2025 KiCad; E.D.A. 8.0.8 Size: A4; Rev:; Id: 1/1 Title: RE_SWC; File: RE_SWC_RevB.kicad_pcb Sheet: BoardInfo POUNAMU; ELECTRONICS; Board2Pdf:; BoardInfo; Page; Layer Name; Loss Tangent; Top Silk; Screen; Castellated; pads:; Black; 3.3 Direct; Printing; copper; Epsilon; Copper; Finish:; F.Mask; No Bottom Solder Mask; FR4 F.Paste; Impedance; Control:; 3.3 Top Solder Mask; Direct; Min hole diameter: Black; 0 Dielectric; Edge card connectors:; Plated Board Edge: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

Min track/spacing:

HAL lead-free

Top Solder Paste | | 1.51 Thickness mm (mm) | Color | 1 B.Mask | 0 F.Cu 0 Material 0

core Bottom Silk Screen Type | | | | | | | | | | 0

Liquid Ink | | | mm 0.035 mm | FR4 natural 0.01 | 0.02

Liquid | | | Ink Bottom Solder Paste | | 0.01 mm

B.Paste | | | | | | | | | 0 mm | 1 B.Silkscreen

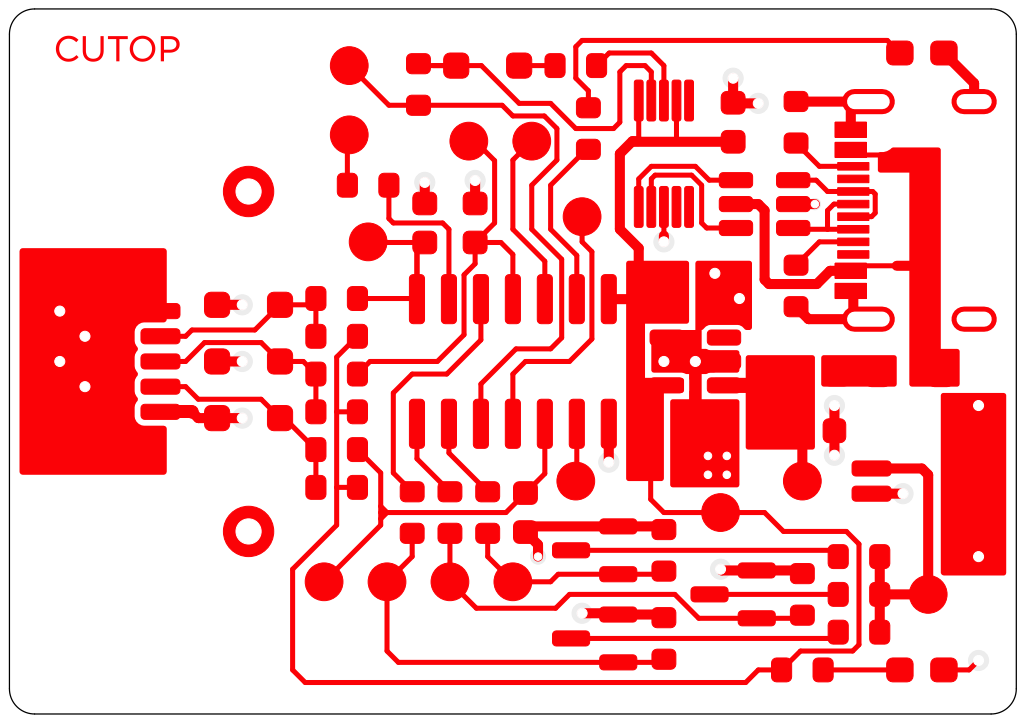
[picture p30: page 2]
6 ABCD; ABCD Date: 08-07-2025 KiCad; E.D.A. 8.0.8 Size: A4; Rev:; POUNAMU; ELECTRONICS; Board2Pdf:; FrontCU -; Page 2/9

File: RE_SWC_RevB.kicad_pcb Sheet: FrontCU
Id: 1/1 Title: RE_SWC

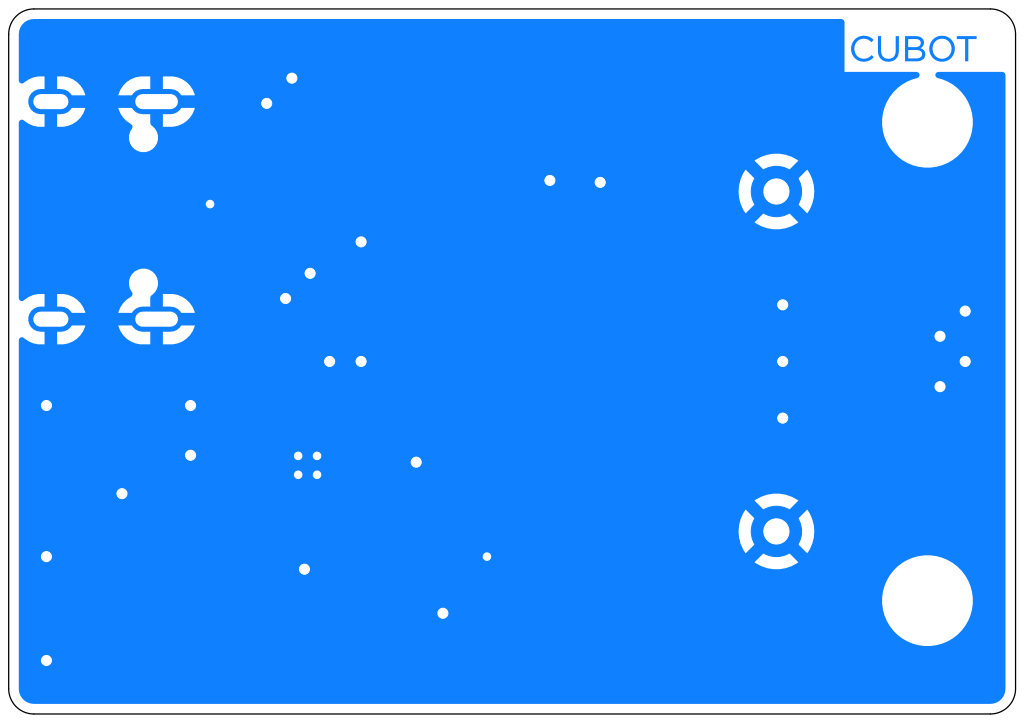
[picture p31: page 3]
6 ABCD; ABCD Date: 08-07-2025 KiCad; E.D.A. 8.0.8 Size: A4; Rev:; POUNAMU; ELECTRONICS; Board2Pdf:; BackCU -; Page 3/9

File: RE_SWC_RevB.kicad_pcb Sheet: BackCU
Id: 1/1 Title: RE_SWC

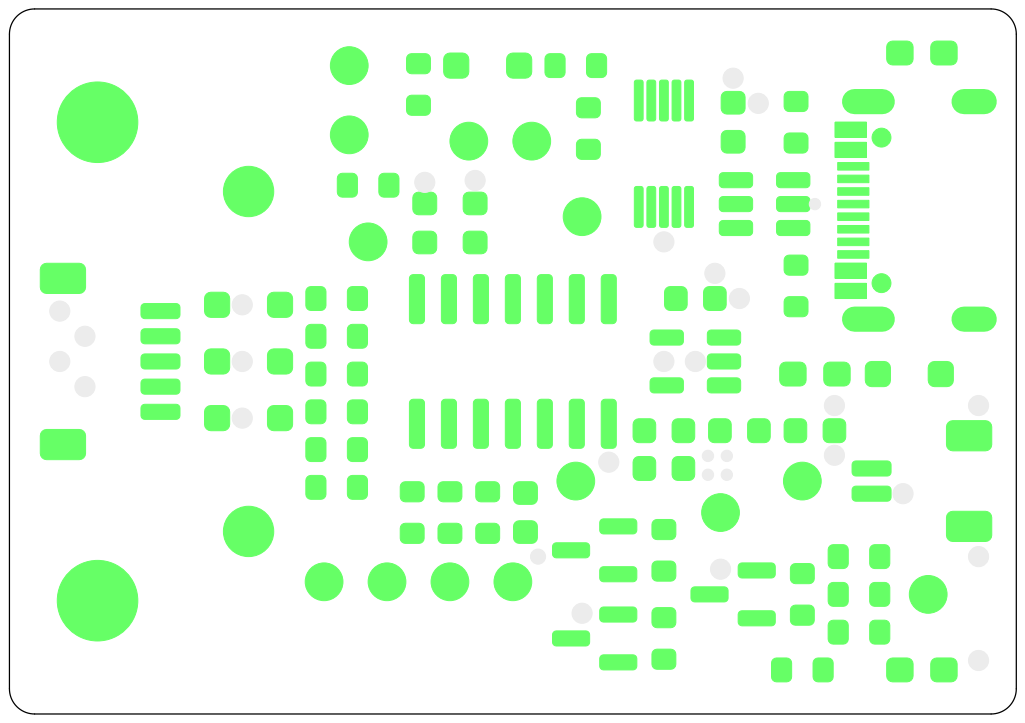
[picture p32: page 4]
6 ABCD; ABCD Date: 08-07-2025 KiCad; E.D.A. 8.0.8 Size: A4; Rev:; Id: 1/1 Title: RE_SWC; File: RE_SWC_RevB.kicad_pcb Sheet: FrontMask POUNAMU; ELECTRONICS; Board2Pdf:; FrontMask; Page 4/9

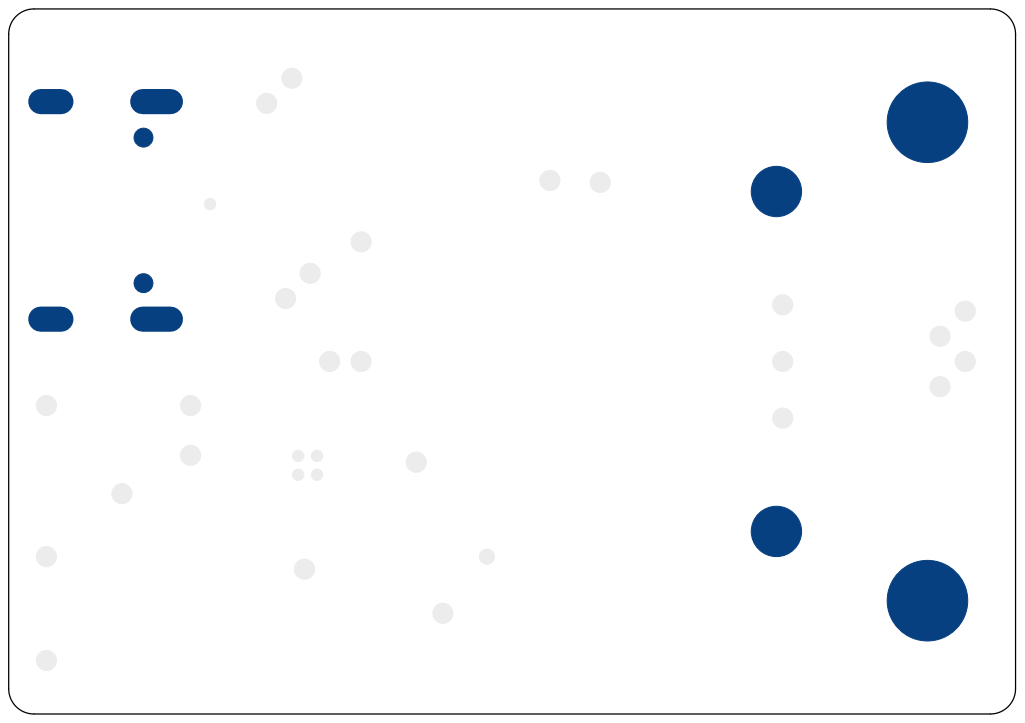
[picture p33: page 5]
6 ABCD; ABCD Date: 08-07-2025 KiCad; E.D.A. 8.0.8 Size: A4; Rev:; Id: 1/1 Title: RE_SWC; File: RE_SWC_RevB.kicad_pcb Sheet: BackMask POUNAMU; ELECTRONICS; Board2Pdf:; BackMask; Page 5/9

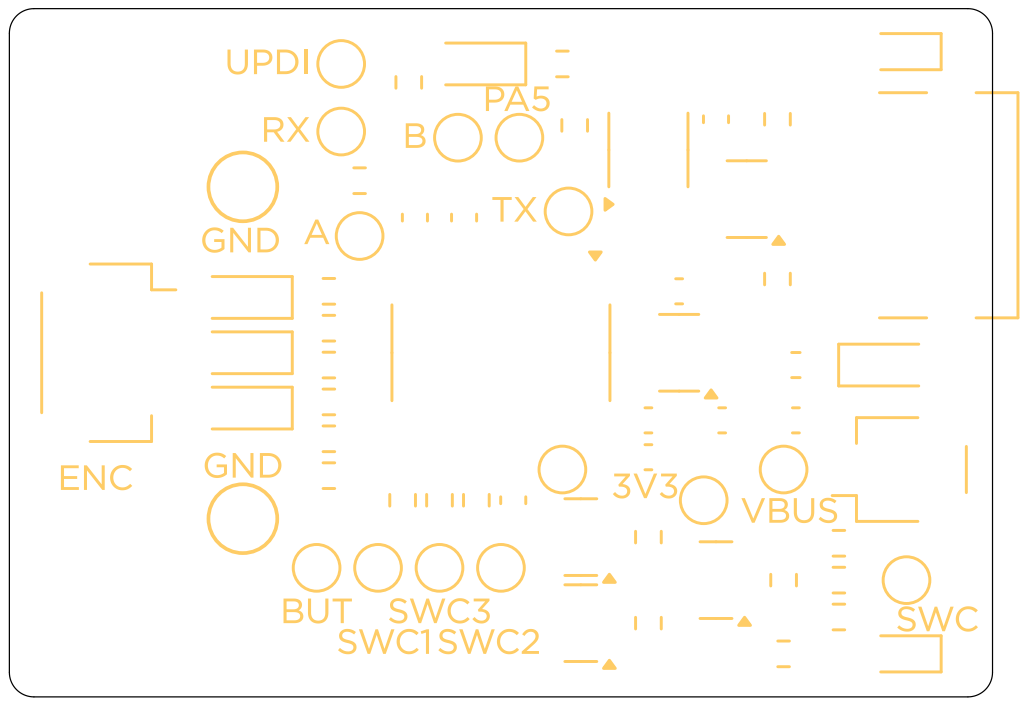
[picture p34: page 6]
6 ABCD; ABCD Date: 08-07-2025 KiCad; E.D.A. 8.0.8 Size: A4; Rev:; POUNAMU; ELECTRONICS; Board2Pdf:; FrontSS -; Page 6/9

File: RE_SWC_RevB.kicad_pcb Sheet: FrontSS
Id: 1/1 Title: RE_SWC

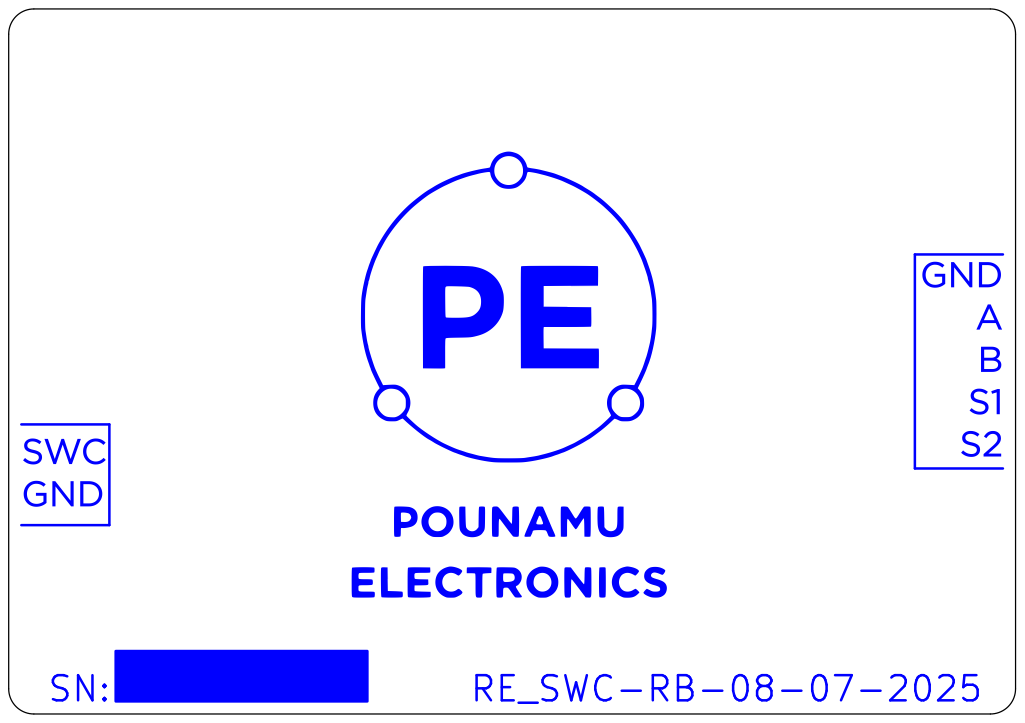
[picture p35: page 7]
6 ABCD; ABCD Date: 08-07-2025 KiCad; E.D.A. 8.0.8 Size: A4; Rev:; POUNAMU; ELECTRONICS; Board2Pdf:; BackSS -; Page 7/9; RE_SWC-RB-08-07-2025

File: RE_SWC_RevB.kicad_pcb Sheet: BackSS
Id: 1/1 Title: RE_SWC

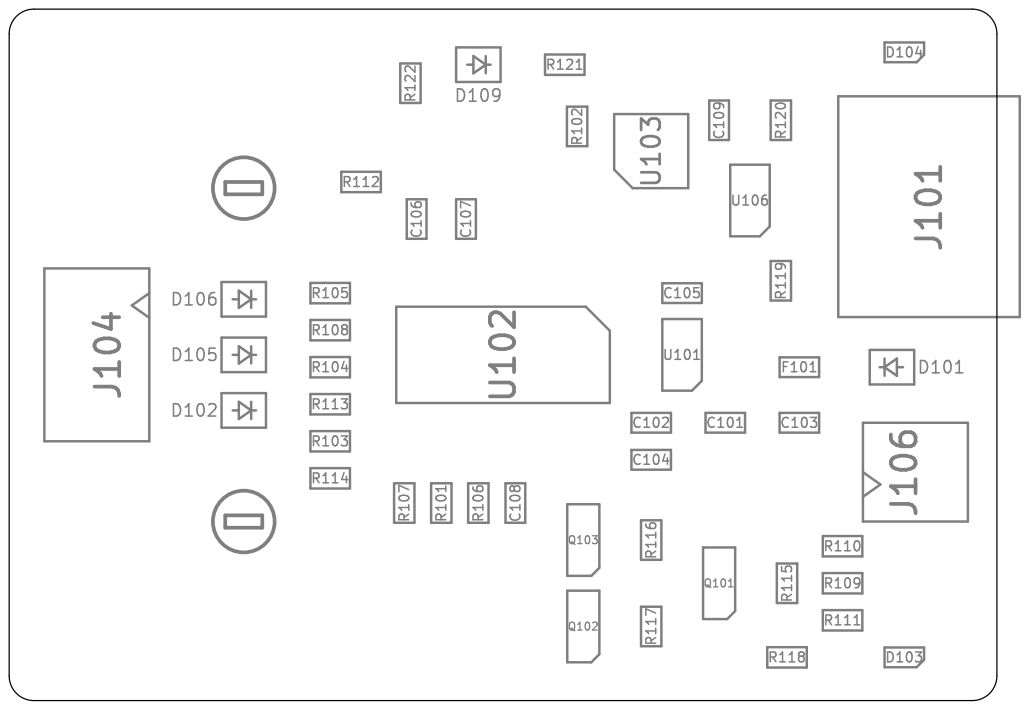
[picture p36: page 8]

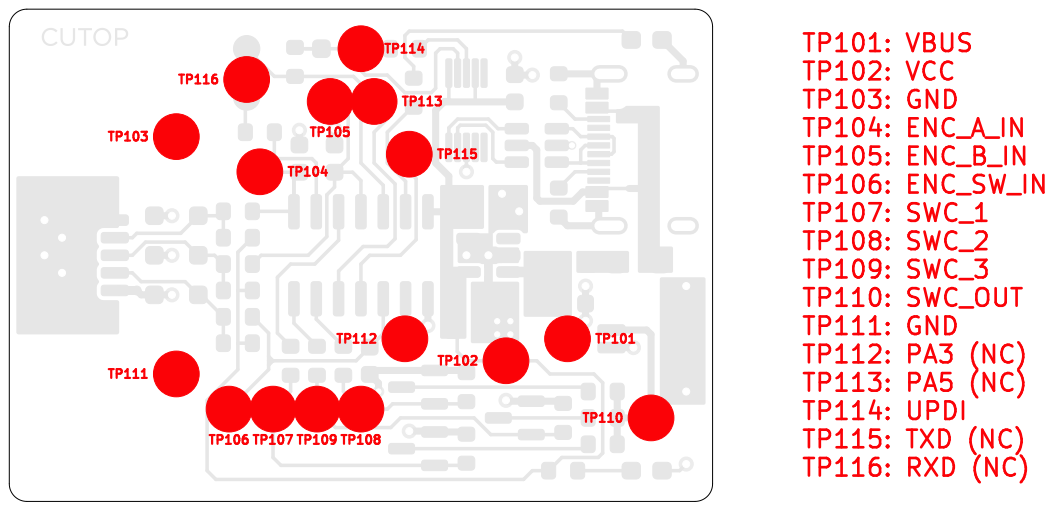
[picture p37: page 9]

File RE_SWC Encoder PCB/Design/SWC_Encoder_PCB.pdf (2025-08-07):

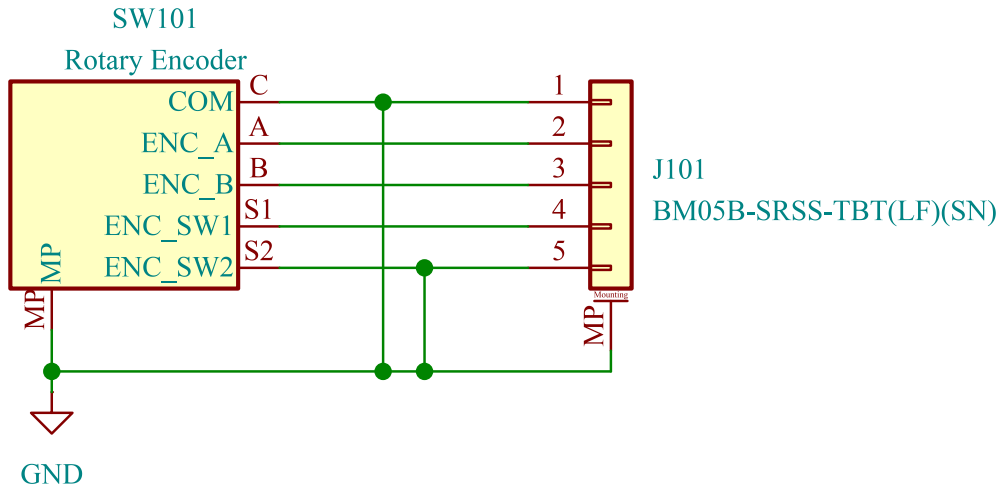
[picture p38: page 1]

J101 BM05B-SRSS-TBT(LF)(SN) GND

Id: 1/1 Title: SWC - EncoderPCB
